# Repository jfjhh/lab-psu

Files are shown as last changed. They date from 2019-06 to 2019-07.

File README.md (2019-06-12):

# Lab Power Supply

This repository contains the KiCAD files and documentation for a simple lab
power supply.

The KiCAD files are in the top level.

The exported gerber and NC drill files are in the `gerbers` directory.

The documentation for the project is in the `doc` directory. This includes:

- KiCAD and DigiKey bills of materials in `doc/bom`.
- Datasheets for all ICs used in `doc/datasheets`.
- PCB layer PDFs in `doc/pcb`.
- A schematic PDF at `doc/psu-schematic.pdf`.
- A comprehensive manual in `doc/manual`.

Note that some parts on hand were used and not included in the DigiKey BOM.
These discrepancies are documented in `doc/bom/non-digikey.txt`.

*The development of this power supply was generously funded by the Reed College
Physics Department during the summer of 2019.*

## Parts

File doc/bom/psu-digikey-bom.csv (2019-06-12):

Manufacturer Part Number | Manufacturer | Digi-Key Part Number | Customer Reference | Reference Designator | Packaging | Part Status | Quantity | Unit Price | Extended Price | Quantity Available | Mfg Std Lead Time | Description | RoHS Status | Lead Free Status | REACH Status
LT3081EFE#PBF | Linear Technology/Analog Devices | LT3081EFE#PBF-ND |  |  | Tube | Active | 1 | 6.48000 | $6.48 | 459 | 8 Weeks | IC REG LIN POS ADJ 1.5A 16TSSOP | RoHS Compliant | Lead free | REACH Unaffected
LM334Z/NOPB | Texas Instruments | LM334ZNS/NOPB-ND |  |  | Box | Active | 1 | 0.87000 | $0.87 | 14066 | 16 Weeks | IC CURRENT SOURCE 3% TO92-3 | RoHS Compliant | Lead free | REACH Unaffected
PJ-002A | CUI Inc. | CP-002A-ND |  |  | Bag | Active | 1 | 0.60000 | $0.60 | 128622 | 10 Weeks | CONN PWR JACK 2X5.5MM SOLDER | RoHS Compliant | Lead free | Not Available
P160KN-0QC15B500K | TT Electronics/BI | 987-1304-ND |  |  | Tray | Active | 1 | 0.79000 | $0.79 | 745 | 10 Weeks | POT 500K OHM 1/5W PLASTIC LINEAR | RoHS Compliant | Lead free | REACH Unaffected
P160KN-0QC15B10K | TT Electronics/BI | 987-1301-ND |  |  | Tray | Active | 1 | 0.79000 | $0.79 | 4716 | 10 Weeks | POT 10K OHM 1/5W PLASTIC LINEAR | RoHS Compliant | Lead free | REACH Unaffected
LM4040EIM3X-2.5/NOPB | Texas Instruments | LM4040EIM3X-2.5/NOPBCT-ND |  |  | Cut Tape (CT) | Active | 1 | 0.44000 | $0.44 | 11631 | 1 Weeks | IC VREF SHUNT 2.5V SOT23-3 | RoHS Compliant | Lead free | REACH Unaffected
SK-14D01-G 6 | C&K | CKN10368-ND |  |  | Bulk | Active | 2 | 0.36000 | $0.72 | 2775 | 13 Weeks | SWITCH SLIDE SP4T 300MA 30V | RoHS Compliant | Lead free | REACH Unaffected
691137710002 | Wurth Electronics Inc. | 732-10955-ND |  |  | Box | Active | 1 | 0.38000 | $0.38 | 3902 | 16 Weeks | TERM BLK 2POS SIDE ENTRY 5MM PCB | RoHS Compliant | Lead free | REACH Unaffected
CL31A106MBHNNNE | Samsung Electro-Mechanics | 1276-6736-1-ND |  |  | Cut Tape (CT) | Active | 2 | 0.30000 | $0.60 | 298978 | Not Available | CAP CER 10UF 50V X5R 1206 | RoHS Compliant | Lead free | REACH Unaffected
TC33X-2-101E | Bourns Inc. | TC33X-101ECT-ND |  |  | Cut Tape (CT) | Active | 1 | 0.28000 | $0.28 | 749 | 18 Weeks | TRIMMER 100 OHM 0.1W J LEAD TOP | RoHS Compliant | Lead free | REACH Unaffected
CRCW12061R80FKEA | Vishay Dale | 541-1.80FFCT-ND |  |  | Cut Tape (CT) | Active | 1 | 0.10000 | $0.10 | 4595 | 14 Weeks | RES SMD 1.8 OHM 1% 1/4W 1206 | RoHS Compliant | Lead free | Not Available
RNCP1206FTD4R70 | Stackpole Electronics Inc | RNCP1206FTD4R70CT-ND |  |  | Cut Tape (CT) | Active | 1 | 0.10000 | $0.10 | 318328 | 18 Weeks | RES 4.7 OHM 1% 1/2W 1206 | RoHS Compliant | Lead free | REACH Unaffected
RC1206FR-0713RL | Yageo | 311-13.0FRCT-ND |  |  | Cut Tape (CT) | Active | 1 | 0.10000 | $0.10 | 205015 | 16 Weeks | RES SMD 13 OHM 1% 1/4W 1206 | RoHS Compliant | Lead free | REACH Unaffected
RMCF1206FT27R0 | Stackpole Electronics Inc | RMCF1206FT27R0CT-ND |  |  | Cut Tape (CT) | Active | 1 | 0.10000 | $0.10 | 18732 | 17 Weeks | RES 27 OHM 1% 1/4W 1206 | RoHS Compliant | Lead free | REACH Unaffected
CRGCQ1206F68R | TE Connectivity Passive Product | A129796CT-ND |  |  | Cut Tape (CT) | Active | 1 | 0.10000 | $0.10 | 63049 | 28 Weeks | CRGCQ 1206 68R 1% | RoHS Compliant | Lead free | Not Available
RNCP1206FTD100R | Stackpole Electronics Inc | RNCP1206FTD100RCT-ND |  |  | Cut Tape (CT) | Active | 2 | 0.10000 | $0.20 | 651800 | 18 Weeks | RES 100 OHM 1% 1/2W 1206 | RoHS Compliant | Lead free | REACH Unaffected
RNCP1206FTD180R | Stackpole Electronics Inc | RNCP1206FTD180RCT-ND |  |  | Cut Tape (CT) | Active | 1 | 0.10000 | $0.10 | 78712 | 18 Weeks | RES 180 OHM 1% 1/2W 1206 | RoHS Compliant | Lead free | REACH Unaffected
RNCP1206FTD1R00 | Stackpole Electronics Inc | RNCP1206FTD1R00CT-ND |  |  | Cut Tape (CT) | Active | 4 | 0.10000 | $0.40 | 600591 | 18 Weeks | RES 1 OHM 1% 1/2W 1206 | RoHS Compliant | Lead free | REACH Unaffected
RMCF1206FT39R0 | Stackpole Electronics Inc | RMCF1206FT39R0CT-ND |  |  | Cut Tape (CT) | Active | 1 | 0.10000 | $0.10 | 16042 | 17 Weeks | RES 39 OHM 1% 1/4W 1206 | RoHS Compliant | Lead free | REACH Unaffected
RC1206FR-071K5L | Yageo | 311-1.50KFRCT-ND |  |  | Cut Tape (CT) | Active | 1 | 0.10000 | $0.10 | 2341272 | 16 Weeks | RES SMD 1.5K OHM 1% 1/4W 1206 | RoHS Compliant | Lead free | REACH Unaffected
CRG1206F1M0 | TE Connectivity Passive Product | A106072CT-ND |  |  | Cut Tape (CT) | Active | 1 | 0.10000 | $0.10 | 190895 | 28 Weeks | RES SMD 1M OHM 1% 1/4W 1206 | RoHS Compliant | Lead free | Not Available
RC1206FR-0724KL | Yageo | 311-24.0KFRCT-ND |  |  | Cut Tape (CT) | Active | 1 | 0.10000 | $0.10 | 233935 | 16 Weeks | RES SMD 24K OHM 1% 1/4W 1206 | RoHS Compliant | Lead free | REACH Unaffected
RNCP1206FTD1K00 | Stackpole Electronics Inc | RNCP1206FTD1K00CT-ND |  |  | Cut Tape (CT) | Active | 2 | 0.10000 | $0.20 | 566298 | 18 Weeks | RES 1K OHM 1% 1/2W 1206 | RoHS Compliant | Lead free | REACH Unaffected
RMCF1206FT150K | Stackpole Electronics Inc | RMCF1206FT150KCT-ND |  |  | Cut Tape (CT) | Active | 1 | 0.10000 | $0.10 | 58922 | 17 Weeks | RES 150K OHM 1% 1/4W 1206 | RoHS Compliant | Lead free | REACH Unaffected
RMCF1206FT10K0 | Stackpole Electronics Inc | RMCF1206FT10K0CT-ND |  |  | Cut Tape (CT) | Active | 2 | 0.10000 | $0.20 | 1066955 | 17 Weeks | RES 10K OHM 1% 1/4W 1206 | RoHS Compliant | Lead free | REACH Unaffected
LM393ADR | Texas Instruments | 296-14605-1-ND |  |  | Cut Tape (CT) | Active | 1 | 0.36000 | $0.36 | 87570 | 1 Weeks | IC DUAL DIFF COMPARATOR 8-SOIC | RoHS Compliant | Lead free | REACH Unaffected
TC33X-2-504E | Bourns Inc. | TC33X-2-504ECT-ND |  |  | Cut Tape (CT) | Active | 1 | 0.28000 | $0.28 | 10204 | 18 Weeks | TRIMMER 500K OHM 0.1W J LEAD TOP | RoHS Compliant | Lead free | REACH Unaffected
LM317LCLP | Texas Instruments | 296-33312-5-ND |  |  | Bulk | Active | 2 | 0.43000 | $0.86 | 3029 | 16 Weeks | IC REG LIN POS ADJ 100MA TO92-3 | RoHS Compliant | Lead free | REACH Unaffected
111-0702-001 | Cinch Connectivity Solutions Johnson | J10125-ND |  |  | Bulk | Active | 1 | 3.57000 | $3.57 | 5967 | 6 Weeks | CONN BIND POST KNURLED RED | RoHS Compliant | Lead free | Not Available
111-0703-001 | Cinch Connectivity Solutions Johnson | J10126-ND |  |  | Bulk | Active | 1 | 2.98000 | $2.98 | 3052 | 6 Weeks | CONN BIND POST KNURLED BLACK | RoHS Compliant | Lead free | Not Available
151031SS06000 | Wurth Electronics Inc. | 732-5006-ND |  |  | Bulk | Active | 2 | 0.17000 | $0.34 | 5963 | 19 Weeks | LED RED DIFFUSED 3MM ROUND T/H | RoHS Compliant | Lead free | REACH Unaffected

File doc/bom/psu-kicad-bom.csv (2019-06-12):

Source: | /home/jfjhh/projects/lab-psu/psu.sch
Date: | Wed 12 Jun 2019 11:53:36 AM PDT
Tool: | Eeschema 5.1.0
Generator: | /usr/share/kicad/plugins/bom_csv_grouped_by_value.py
Component Count: | 60
Individual Components:
Item | Qty | Reference(s) | Value | LibPart | Footprint | Datasheet
 |  | C1 | 0u1 | Device:C_Small | Capacitor_THT:C_Disc_D5.0mm_W2.5mm_P2.50mm | ~
 |  | C2 | 0u1 | Device:C_Small | Capacitor_THT:C_Disc_D5.0mm_W2.5mm_P2.50mm | ~
 |  | C3 | 10u | Device:C_Small | Capacitor_SMD:C_1206_3216Metric_Pad1.42x1.75mm_HandSolder | ~
 |  | C4 | 10u | Device:C_Small | Capacitor_SMD:C_1206_3216Metric_Pad1.42x1.75mm_HandSolder | ~
 |  | C5 | 0u1 | Device:C_Small | Capacitor_THT:C_Disc_D5.0mm_W2.5mm_P2.50mm | ~
 |  | C6 | 0u1 | Device:C_Small | Capacitor_THT:C_Disc_D5.0mm_W2.5mm_P2.50mm | ~
 |  | C7 | 0u1 | Device:C_Small | Capacitor_THT:C_Disc_D5.0mm_W2.5mm_P2.50mm | ~
 |  | C8 | 0u1 | Device:C_Small | Capacitor_THT:C_Disc_D5.0mm_W2.5mm_P2.50mm | ~
 |  | D1 | LED_RED | Device:LED_ALT | LED_THT:LED_D3.0mm | ~
 |  | D2 | LED_RED | Device:LED_ALT | LED_THT:LED_D3.0mm | ~
 |  | J1 | Screw_Terminal_01x02 | Connector:Screw_Terminal_01x02 | TerminalBlock_MetzConnect:TerminalBlock_MetzConnect_Type094_RT03502HBLU_1x02_P5.00mm_Horizontal | ~
 |  | J2 | Barrel_Jack | Connector:Barrel_Jack | Connector_BarrelJack:BarrelJack_Horizontal | ~
 |  | J3 | Binding posts | Connector_Generic:Conn_01x02 | psu-foot:Binding Posts | ~
 |  | JP1 | Min Lim | Device:Jumper_NO_Small | Connector_PinHeader_2.54mm:PinHeader_1x02_P2.54mm_Vertical | ~
 |  | JP2 | No limit | Device:Jumper_NO_Small | Connector_PinHeader_2.54mm:PinHeader_1x02_P2.54mm_Vertical | ~
 |  | JP3 | Preload | Device:Jumper_NO_Small | Connector_PinHeader_2.54mm:PinHeader_1x02_P2.54mm_Vertical | ~
 |  | JP4 | Guard | Device:Jumper_NO_Small | psu-foot:Guard_Jumper | ~
 |  | JP5 | Guard | Device:Jumper_NO_Small | psu-foot:Guard_Jumper | ~
 |  | R1 | 1R8 | Device:R | Resistor_SMD:R_1206_3216Metric_Pad1.42x1.75mm_HandSolder | ~
 |  | R2 | 4R7 | Device:R | Resistor_SMD:R_1206_3216Metric_Pad1.42x1.75mm_HandSolder | ~
 |  | R3 | 13R | Device:R | Resistor_SMD:R_1206_3216Metric_Pad1.42x1.75mm_HandSolder | ~
 |  | R4 | 27R | Device:R | Resistor_SMD:R_1206_3216Metric_Pad1.42x1.75mm_HandSolder | ~
 |  | R5 | 68R | Device:R | Resistor_SMD:R_1206_3216Metric_Pad1.42x1.75mm_HandSolder | ~
 |  | R6 | 100R | Device:R | Resistor_SMD:R_1206_3216Metric_Pad1.42x1.75mm_HandSolder | ~
 |  | R7 | 180R | Device:R | Resistor_SMD:R_1206_3216Metric_Pad1.42x1.75mm_HandSolder | ~
 |  | R8 | 1R0 | Device:R | Resistor_SMD:R_1206_3216Metric_Pad1.42x1.75mm_HandSolder | ~
 |  | R9 | 2R2 | Device:R | Resistor_SMD:R_1206_3216Metric_Pad1.42x1.75mm_HandSolder | ~
 |  | R10 | 1R0 | Device:R | Resistor_SMD:R_1206_3216Metric_Pad1.42x1.75mm_HandSolder | ~
 |  | R11 | 1R0 | Device:R | Resistor_SMD:R_1206_3216Metric_Pad1.42x1.75mm_HandSolder | ~
 |  | R12 | 1R0 | Device:R | Resistor_SMD:R_1206_3216Metric_Pad1.42x1.75mm_HandSolder | ~
 |  | R13 | 39R | Device:R | Resistor_SMD:R_1206_3216Metric_Pad1.42x1.75mm_HandSolder | ~
 |  | R14 | 100R | Device:R | Resistor_SMD:R_1206_3216Metric_Pad1.42x1.75mm_HandSolder | ~
 |  | R15 | 4k7 | Device:R | Resistor_THT:R_Axial_DIN0207_L6.3mm_D2.5mm_P10.16mm_Horizontal | ~
 |  | R16 | 390R | Device:R | Resistor_THT:R_Axial_DIN0207_L6.3mm_D2.5mm_P10.16mm_Horizontal | ~
 |  | R17 | 1k5 | Device:R | Resistor_SMD:R_1206_3216Metric_Pad1.42x1.75mm_HandSolder | ~
 |  | R18 | 1M | Device:R | Resistor_SMD:R_1206_3216Metric_Pad1.42x1.75mm_HandSolder | ~
 |  | R19 | 24k | Device:R | Resistor_SMD:R_1206_3216Metric_Pad1.42x1.75mm_HandSolder | ~
 |  | R20 | 1k | Device:R | Resistor_SMD:R_1206_3216Metric_Pad1.42x1.75mm_HandSolder | ~
 |  | R21 | 150k | Device:R | Resistor_SMD:R_1206_3216Metric_Pad1.42x1.75mm_HandSolder | ~
 |  | R22 | 1k | Device:R | Resistor_THT:R_Axial_DIN0207_L6.3mm_D2.5mm_P10.16mm_Horizontal | ~
 |  | R23 | 22R | Device:R | Resistor_THT:R_Axial_DIN0207_L6.3mm_D2.5mm_P10.16mm_Horizontal | ~
 |  | R24 | 10k | Device:R | Resistor_SMD:R_1206_3216Metric_Pad1.42x1.75mm_HandSolder | ~
 |  | R25 | 10k | Device:R | Resistor_SMD:R_1206_3216Metric_Pad1.42x1.75mm_HandSolder | ~
 |  | R26 | 1k | Device:R | Resistor_SMD:R_1206_3216Metric_Pad1.42x1.75mm_HandSolder | ~
 |  | R27 | 100R | Device:R | Resistor_THT:R_Axial_DIN0207_L6.3mm_D2.5mm_P10.16mm_Horizontal | ~
 |  | R28 | 100R | Device:R | Resistor_THT:R_Axial_DIN0207_L6.3mm_D2.5mm_P10.16mm_Horizontal | ~
 |  | RV1 | 100R | Device:R_POT_US | psu-foot:Trim_pot_Bourns_TC33X-2-101E | ~
 |  | RV2 | 500k | Device:R_POT_US | Potentiometer_THT:Potentiometer_Piher_PC-16_Single_Horizontal | ~
 |  | RV3 | 10k | Device:R_POT_US | Potentiometer_THT:Potentiometer_Piher_PC-16_Single_Horizontal | ~
 |  | RV4 | 1k | Device:R_POT_US | Potentiometer_THT:Potentiometer_Piher_PC-16_Single_Horizontal | ~
 |  | RV5 | 500k | Device:R_POT_US | psu-foot:Trim_pot_Bourns_TC33X-2-101E | ~
 |  | SW1 | SW_SP4T | psu-sch:SW_SP4T | psu-foot:SP4T_CK_SK-14D01-G-6 | ~
 |  | SW2 | SW_SP4T | psu-sch:SW_SP4T | psu-foot:SP4T_CK_SK-14D01-G-6 | ~
 |  | SW3 | Lever toggle | Switch:SW_SPST | psu-foot:SW_SPST_Lever_Rubber | ~
 |  | U1 | LM4040DBZ-2.5 | Reference_Voltage:LM4040DBZ-2.5 | Package_TO_SOT_SMD:SOT-23 | http://www.ti.com/lit/ds/symlink/lm4040-n.pdf
 |  | U2 | LT3081 | psu-sch:LT3081 | Package_SO:HTSSOP-16-1EP_4.4x5mm_P0.65mm_EP3.4x5mm_Mask3x3mm_ThermalVias | https://www.analog.com/media/en/technical-documentation/data-sheets/3081fc.pdf
 |  | U3 | LM393 | Comparator:LM393 | Package_SO:SOIC-8_3.9x4.9mm_P1.27mm | http://www.ti.com/lit/ds/symlink/lm393-n.pdf
 |  | U4 | LM334M | Reference_Current:LM334M | Package_SO:SOIC-8_3.9x4.9mm_P1.27mm | http://www.ti.com/lit/ds/symlink/lm134.pdf
 |  | U5 | LM317L_TO92 | Regulator_Linear:LM317L_TO92 | Package_TO_SOT_THT:TO-92_Inline | http://www.ti.com/lit/ds/symlink/lm317l.pdf
 |  | U6 | LM317L_TO92 | Regulator_Linear:LM317L_TO92 | Package_TO_SOT_THT:TO-92_Inline | http://www.ti.com/lit/ds/symlink/lm317l.pdf
Collated Components:
Item | Qty | Reference(s) | Value | LibPart | Footprint | Datasheet
1 | 6 | C1, C2, C5, C6, C7, C8 | 0u1 | Device:C_Small | Capacitor_THT:C_Disc_D5.0mm_W2.5mm_P2.50mm | ~
2 | 2 | C3, C4 | 10u | Device:C_Small | Capacitor_SMD:C_1206_3216Metric_Pad1.42x1.75mm_HandSolder | ~
3 | 2 | D1, D2 | LED_RED | Device:LED_ALT | LED_THT:LED_D3.0mm | ~
4 | 1 | J1 | Screw_Terminal_01x02 | Connector:Screw_Terminal_01x02 | TerminalBlock_MetzConnect:TerminalBlock_MetzConnect_Type094_RT03502HBLU_1x02_P5.00mm_Horizontal | ~
5 | 1 | J2 | Barrel_Jack | Connector:Barrel_Jack | Connector_BarrelJack:BarrelJack_Horizontal | ~
6 | 1 | J3 | Binding posts | Connector_Generic:Conn_01x02 | psu-foot:Binding Posts | ~
7 | 1 | JP1 | Min Lim | Device:Jumper_NO_Small | Connector_PinHeader_2.54mm:PinHeader_1x02_P2.54mm_Vertical | ~
8 | 1 | JP2 | No limit | Device:Jumper_NO_Small | Connector_PinHeader_2.54mm:PinHeader_1x02_P2.54mm_Vertical | ~
9 | 1 | JP3 | Preload | Device:Jumper_NO_Small | Connector_PinHeader_2.54mm:PinHeader_1x02_P2.54mm_Vertical | ~
10 | 2 | JP4, JP5 | Guard | Device:Jumper_NO_Small | psu-foot:Guard_Jumper | ~
11 | 1 | R1 | 1R8 | Device:R | Resistor_SMD:R_1206_3216Metric_Pad1.42x1.75mm_HandSolder | ~
12 | 1 | R2 | 4R7 | Device:R | Resistor_SMD:R_1206_3216Metric_Pad1.42x1.75mm_HandSolder | ~
13 | 1 | R3 | 13R | Device:R | Resistor_SMD:R_1206_3216Metric_Pad1.42x1.75mm_HandSolder | ~
14 | 1 | R4 | 27R | Device:R | Resistor_SMD:R_1206_3216Metric_Pad1.42x1.75mm_HandSolder | ~
15 | 1 | R5 | 68R | Device:R | Resistor_SMD:R_1206_3216Metric_Pad1.42x1.75mm_HandSolder | ~
16 | 2 | R6, R14 | 100R | Device:R | Resistor_SMD:R_1206_3216Metric_Pad1.42x1.75mm_HandSolder | ~
17 | 1 | R7 | 180R | Device:R | Resistor_SMD:R_1206_3216Metric_Pad1.42x1.75mm_HandSolder | ~
18 | 4 | R8, R10, R11, R12 | 1R0 | Device:R | Resistor_SMD:R_1206_3216Metric_Pad1.42x1.75mm_HandSolder | ~
19 | 1 | R9 | 2R2 | Device:R | Resistor_SMD:R_1206_3216Metric_Pad1.42x1.75mm_HandSolder | ~
20 | 1 | R13 | 39R | Device:R | Resistor_SMD:R_1206_3216Metric_Pad1.42x1.75mm_HandSolder | ~
21 | 1 | R15 | 4k7 | Device:R | Resistor_THT:R_Axial_DIN0207_L6.3mm_D2.5mm_P10.16mm_Horizontal | ~
22 | 1 | R16 | 390R | Device:R | Resistor_THT:R_Axial_DIN0207_L6.3mm_D2.5mm_P10.16mm_Horizontal | ~
23 | 1 | R17 | 1k5 | Device:R | Resistor_SMD:R_1206_3216Metric_Pad1.42x1.75mm_HandSolder | ~
24 | 1 | R18 | 1M | Device:R | Resistor_SMD:R_1206_3216Metric_Pad1.42x1.75mm_HandSolder | ~
25 | 1 | R19 | 24k | Device:R | Resistor_SMD:R_1206_3216Metric_Pad1.42x1.75mm_HandSolder | ~
26 | 2 | R20, R26 | 1k | Device:R | Resistor_SMD:R_1206_3216Metric_Pad1.42x1.75mm_HandSolder | ~
27 | 1 | R21 | 150k | Device:R | Resistor_SMD:R_1206_3216Metric_Pad1.42x1.75mm_HandSolder | ~
28 | 1 | R22 | 1k | Device:R | Resistor_THT:R_Axial_DIN0207_L6.3mm_D2.5mm_P10.16mm_Horizontal | ~
29 | 1 | R23 | 22R | Device:R | Resistor_THT:R_Axial_DIN0207_L6.3mm_D2.5mm_P10.16mm_Horizontal | ~
30 | 2 | R24, R25 | 10k | Device:R | Resistor_SMD:R_1206_3216Metric_Pad1.42x1.75mm_HandSolder | ~
31 | 2 | R27, R28 | 100R | Device:R | Resistor_THT:R_Axial_DIN0207_L6.3mm_D2.5mm_P10.16mm_Horizontal | ~
32 | 1 | RV1 | 100R | Device:R_POT_US | psu-foot:Trim_pot_Bourns_TC33X-2-101E | ~
33 | 1 | RV2 | 500k | Device:R_POT_US | Potentiometer_THT:Potentiometer_Piher_PC-16_Single_Horizontal | ~
34 | 1 | RV3 | 10k | Device:R_POT_US | Potentiometer_THT:Potentiometer_Piher_PC-16_Single_Horizontal | ~
35 | 1 | RV4 | 1k | Device:R_POT_US | Potentiometer_THT:Potentiometer_Piher_PC-16_Single_Horizontal | ~
36 | 1 | RV5 | 500k | Device:R_POT_US | psu-foot:Trim_pot_Bourns_TC33X-2-101E | ~
37 | 2 | SW1, SW2 | SW_SP4T | psu-sch:SW_SP4T | psu-foot:SP4T_CK_SK-14D01-G-6 | ~
38 | 1 | SW3 | Lever toggle | Switch:SW_SPST | psu-foot:SW_SPST_Lever_Rubber | ~
39 | 1 | U1 | LM4040DBZ-2.5 | Reference_Voltage:LM4040DBZ-2.5 | Package_TO_SOT_SMD:SOT-23 | http://www.ti.com/lit/ds/symlink/lm4040-n.pdf
40 | 1 | U2 | LT3081 | psu-sch:LT3081 | Package_SO:HTSSOP-16-1EP_4.4x5mm_P0.65mm_EP3.4x5mm_Mask3x3mm_ThermalVias | https://www.analog.com/media/en/technical-documentation/data-sheets/3081fc.pdf
41 | 1 | U3 | LM393 | Comparator:LM393 | Package_SO:SOIC-8_3.9x4.9mm_P1.27mm | http://www.ti.com/lit/ds/symlink/lm393-n.pdf
42 | 1 | U4 | LM334M | Reference_Current:LM334M | Package_SO:SOIC-8_3.9x4.9mm_P1.27mm | http://www.ti.com/lit/ds/symlink/lm134.pdf
43 | 2 | U5, U6 | LM317L_TO92 | Regulator_Linear:LM317L_TO92 | Package_TO_SOT_THT:TO-92_Inline | http://www.ti.com/lit/ds/symlink/lm317l.pdf

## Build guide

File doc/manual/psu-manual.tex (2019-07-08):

\documentclass[letterpaper,twocolumn,11pt]{article}

\usepackage[utf8]{inputenc}
\usepackage[T1]{fontenc}
\usepackage{amsmath}
\usepackage{amssymb}
\usepackage{amsthm}
\usepackage{booktabs}
\usepackage[labelfont=bf]{caption}
\usepackage[american]{circuitikz}
\usepackage{enumitem}
\usepackage{float}
\usepackage{geometry}
\usepackage{graphicx}
\usepackage{hyperref}
\usepackage{mathtools}
\usepackage{microtype}
\usepackage{nicefrac}
\usepackage{pdfpages}
\usepackage{physics}
\usepackage{rotating}
\usepackage{siunitx}
\usepackage{xcolor}

\geometry{margin=1in}

\newcommand{\refdes}[1]{\texttt{#1}}
\newcommand{\wtemp}{\ensuremath{\blacklozenge}}

% \renewcommand{\includepdf}{}

\title{Lab Power Supply Manual \\ \large Rev. B}
\author{Alex Striff}
\date{\today}

\begin{document}
\maketitle
\tableofcontents
\listoftables
\thispagestyle{empty}

\section*{Colophon}

The schematic diagram and printed circuit board layout were both created with
KiCAD. This manual was compiled using \LaTeX. Relatively fine (\SI{0.51}{\mm})
lead-based solder and mildly activated rosin flux were required to solder the
components to the PCB.

\section{Acknowledgments}

The creation of this lab power supply was generously funded by the Reed College
Physics Department. I would like to thank Edgar Perez for his kind advice, as
well as Lucas Illing for supporting this project.

\section{Motivation}

Often when working in electronics, several voltage sources are needed. In
addition to a main power rail, one may need a complementary negative power rail
for analog circuitry, or a different logic power supply at \SI{3.3}{\V} instead
of \SI{5}{\V}. Low-impedance bias voltages are also a frequent requirement,
needed for biasing BJTs, comparator inputs, and more.

For most applications, a power supply fulfilling the requirements of these
applications need not be capable of supplying much more than \SI{1}{\A} of
current, must have a stable voltage output (requiring a linear regulator), and
must have a current limiting function.  Additionally, it would be nice if the
power supply was much smaller than a conventional \SI{30}{\V}, \SI{3}{\A} output
bench power supply with a large transformer, being conveniently powered from a
common wall plug, batteries, or any other DC power source at hand. I have
attempted to construct such a power supply.

\section{Safety Notice (Grounding)}

Please note that the negative voltage output of the supply is directly connected
to the negative voltage input to the supply. That is, the output voltage of the
supply floating relative to earth ground if and only if the input voltage is
floating.

If you are uncertain if the supply (or any other piece of equipment) is
floating, it is quick and simple to check if this is the case. Set a digital
multimeter to its resistance measurement or continuity check mode. Connect one
probe to the negative output of the PSU (the black five-way binding post) or to
the other terminal in question, and then connect the other probe to earth
ground. This can be done either by insertion in to the \emph{earth} socket of a
wall outlet, or by touching the outside of a BNC connector on any nearby
oscilloscopes, as these are almost always earth grounded. If inserting into a
wall outlet, be certain that you know which hole is which, and that you are
using a multimeter approved for wall testing (most are).

If the output is not floating (earth-referenced), then one must be careful to
only connect oscilloscope ground leads to the negative output of the supply.
Whatever the ground lead is connected to will be shorted to earth ground. If an
incorrect connection is made, then connected circuit components, oscilloscopes,
or computers (\textit{e.g.} through USB) may be damaged. If you are uncertain,
connect probes as if the circuit is not floating.

If the output is floating (or if you know which terminals are earthed and which
are not), then the supply may be safely connected to other voltage sources in
whatever configurations are convenient, such as in a dual-rail setup.

\section{Usage Instructions}

\subsection{Setting the output voltage}

Connect a voltmeter to the output of the supply. You may use either the binding
posts or the test points labeled on the board to achieve this. Turn the PSU on
and adjust the voltage using the \emph{coarse} and \emph{fine} adjustment knobs
as needed. Note that the maximum output voltage is about \SI{1.5}{\V} below the
input voltage.

\subsection{Setting the current limit}\label{sec:set_limit}

To set the current limit to its minimum value, \emph{short} the minimum limit
jumper (labeled \emph{Min Lim}, \refdes{JP1}). To set the current limit to
higher than this value, the jumper must be \emph{open}.

The current limit is set to fixed values by moving the switches on the
board. The default values are 1, 2.5, 5, 10, 25, 50, and \SI{100}{\mA}. To set
the limit to any of the upper four values, the switch for the lower values must
be in its rightmost position, as indicated on the board.

Alternatively, the switch section on the board may not be populated, and a
\SI{10}{\kohm} (preferably 10-turn) potentiometer (\refdes{RV4}) may be
soldered in to provide a continuously variable current limit.

To set the current limit to its maximum value, \emph{open} the no limit jumper
(labeled \emph{No Limit}, \refdes{JP2}). To set the current limit to lower than
this value, the jumper must be \emph{shorted}. The maximum value is about
\SI{2.0}{\A} in normal operation, and less when the device shuts down to prevent
overheating.

\subsection{Indicator LEDs}

The power supply includes two indicator LEDs for when output voltage regulation
is not guaranteed.

The \textit{Hot} indicator LED (\refdes{D2}) lights when the main regulation IC
(see Section~\ref{sec:lt3081}) starts to get hot (when the junction temperature
is about \SI{100}{\celsius} or above). This light is a warning, and the output
should continue to be regulated as normal. If the IC continues to heat up (to a
junction temperature of \SI{125}{\celsius}), then internal protection circuitry
will prevent damage and reduce the output voltage.

The \textit{$V_\text{out}$ Error ($I$ lim)} indicator LED (\refdes{D1}) lights
when the actual output voltage is not sufficiently close to the set output
voltage. The most common cause for this is if the current limiting function is
active, but internal protection circuitry or a set voltage that is too high may
also cause an output error.

\subsection{Monitoring the output current}

If it is not preferred to use an ammeter to measure the output current, the
\textit{$I_\text{out}$} test point is provided for convenient measurement or
external control of the load current. The signal at \textit{$I_\text{out}$}
is one volt for every ampere of output current, \emph{including the internal
load} (see Table~\ref{tab:chars} and Section~\ref{sec:int_load}). For example,
if the supply is outputting \SI{25}{\mA} total, then \textit{$I_\text{out}$}
should read \SI{25}{\mV}.

\subsection{Monitoring the internal temperature}

For more quantitative information about the temperature of the main regulation
IC (see Section~\ref{sec:lt3081}) than is provided by the \textit{Hot} indicator
LED, the \textit{Temp} test point is provided. The signal at \textit{Temp} is
one millivolt for every degree Celsius of junction temperature. For example, if
the junction temperature of the IC is about \SI{73}{\celsius} (subject to
variation inside the IC), then \textit{Temp} should read \SI{73}{\mV}.

\subsection{Disabling the internal load}

The internal load may be disabled by \emph{opening} the \textit{Internal Load}
jumper.  Note that this will increase the current limit by at most \SI{4}{\mA}
above the current limit displayed on the switches or that previously set by
\refdes{RV4}, if installed. For most purposes, the \textit{Internal Load} jumper
should be in its normal, \emph{shorted} position (see
Section~\ref{sec:int_load}).

\subsection{Calibrating the current limit}

The power supply requires a minimum load in order to regulate the output voltage
properly. An internal load usually supplies this minimum load (see
Section~\ref{sec:int_load}), but this offsets the effective current limit on the
output. A trimmer potentiometer is provided to compensate for this offset.

First, choose which current limit range you most value precision on, say
the \SI{10}{\mA} range. Set the supply to a relatively low voltage, like
\SI{1}{\V}, and place the appropriate load on the output of the supply with a
potentiometer. In this case, we would adjust a potentiometer until it drew
\SI{10}{\mA} through itself. The \textit{$V_\text{out}$ Error ($I$ lim)}
indicator LED should be off. Measuring \textit{$I_\text{out}$} should show
about \SI{13}{\mV}, corresponding the \SI{10}{\mA} external load and the (fixed)
\SI{3}{\mA} internal load. Using a screwdriver, adjust the potentiometer (labeled \emph{Load
Offset}, \refdes{RV1}) until the output voltage is stable (no current limiting),
and then carefully reverse direction and adjust until the current limit just
starts to activate. This may be judged by checking the output voltage with a
voltmeter, or by using the built-in indicator if it is calibrated as described
in Section~\ref{sec:cal_offset}. If using a voltmeter (the more precise method),
aim for a limit situation where the output is about \SI{10}{\mV} below the set
(stable) voltage.

\subsection{Calibrating the output error indicator}\label{sec:cal_offset}

The issues associated with creating a reliable output error indicator are
discussed in Section~\ref{sec:how_offset}. If necessary, a trimmer potentiometer
(\refdes{RV5}) may be populated to correct the default setting by the resistor
\refdes{R21}.

Attach a voltmeter to the PSU and set the output voltage to \SI{1}{\V}. Attach
an external potentiometer to the output of the supply, valued to draw a typical
current for your application. Set the PSU current limit so that increasing the
load current will trigger the limit function. If the \SI{1}{\V} output does not
demand enough current, it may be increased, but try to keep it as low as
possible (see \ref{sec:how_offset} for why). Wait until the temperature of the
circuit has stabilized. Error on the side of drawing a slightly lower current
than needed, depending on the sensitivity required (see below). Increase the
load gradually, and watch the error indicator LED (\refdes{D1}).

If the default indication threshold set by \refdes{R21} is not sensitive enough
for your needs, solder in the \SI{500}{\kohm} \refdes{RV5} and try the
adjustment procedure below.

If this does not work, or if the default indication did not work at all, solder
in \refdes{RV5} and \emph{remove} \refdes{R21}. This provides a wider range of
variation for the indication threshold, at the cost of a coarser adjustment
rate.

With the potentiometer \refdes{RV5} and the default resistor \refdes{R21}
soldered on the board or not depending on your needs, adjust the external load
potentiometer until the output is 2 -- \SI{10}{\mV} below the set voltage. If
you intend to use the supply \emph{only} above about \SI{5}{\V}, the lower the
better (you may even be able to remove \refdes{RV5} and wire a short across
\refdes{R21} for a bit more sensitivity). To complete the calibration, adjust
\refdes{RV5} to the barrier where \refdes{D1} just barely lights, or perhaps
flickers.

% \section{Electrical Characteristics}

\begin{table*}[ht]
  \centering
  \caption[Electrical Characteristics]{Electrical characteristics. The \wtemp\
    mark indicates specifications which apply over the full operating
    temperature range. Otherwise, specifications are at (junction) temperatures
    of \SI{25}{\celsius}. Note that application of negative input voltages may
    damage the supply. Specifically, such damage tends to disable any current
    limiting functionality, while maintaining the capability for voltage
  regulation.}
  \resizebox{\textwidth}{!}{%
    \begin{tabular}{lr|lr|cccr}
      \toprule
      \multicolumn{2}{c}{\textbf{Parameter}} &
      \multicolumn{2}{c}{\textbf{Conditions}} & \textbf{Min} & \textbf{Typ} &
      \textbf{Max} & \multicolumn{1}{c}{\textbf{Units}} \\
      \midrule
      Input Voltage & $V_\text{in}$ & & \wtemp & 5.0 & & 32.0 & \si{\V} \\

      Output Voltage & $V_\text{out}$
      & $I_\text{load} < I_\text{lim}$, $V_\text{in} < \SI{16}{\V}$ & \wtemp
      & 0.7 & & $V_\text{in} - V_\text{do}$ & \si{\V} \\
      &
      & $I_\text{load} < I_\text{lim}$, $V_\text{in} \ge \SI{16}{\V} & \wtemp
      & 0.7 & & 16 & \si{\V} \\
      &
      & No internal load & \wtemp
      & 0.0 & & & \si{\V} \\

      Dropout Voltage & $V_\text{do}$
      & $I_\text{load} = \SI{100}{\mA}$ & & & 1.21 & & \si{\V} \\
      &
      & $I_\text{load} = \SI{1.5}{\A}$ & \wtemp & & 1.23 & 1.5 & \si{\V} \\

      Internal Current Limit & $I_\text{max}$ & $V_\text{in} = \SI{5}{\V}$,
      $V_\text{set} = \SI{0}{\V}$, $V_\text{out} = \SI{-0.1}{\V}$ & \wtemp
      & 1.5 & 2.0 & & \si{\A} \\

      $I_\text{out}$ Relative Error & & $I_\text{load} = \SI{1.5}{\A}$ &
      & 0 & 6 & 11 & \si{\percent} \\

      $I_\text{out}$ Operating Range & & & \wtemp
      & $V_\text{out} - \SI{40}{\V}$ & & $V_\text{out} + \SI{0.4}{\V}$
      & \si{\V} \\

      \textit{Temp} Absolute Error &
      & $\SI{0}{\celsius} \le T_J \le \SI{125}{\celsius}$ &
      & -10 & & 10 & \si{\uA} \\
      &
      & $\SI{125}{\celsius} < T_J \le \SI{150}{\celsius}$ &
      & -15 & & 15 & \si{\uA} \\

      Ripple Rejection
      & PSRR & $f = \SI{120}{\Hz}$ & & 75 & 90 & & \si{\dB} \\

      $V_\text{ripple} = \SI{0.5}{V_{\text{pp}}}$,
      $I_\text{load} = \SI{0.1}{\A}$, &
      & $f = \SI{10}{\kHz}$ & & & 75 & & \si{\dB} \\

      $V_\text{in} = V_\text{out(nom)} + \SI{3}{\V}$ &
      & $f = \SI{1}{\MHz}$ & & & 20 & & \si{\dB} \\

      Internal Load & $I_\text{int}$ & & \wtemp & 2 & 3 & 4 & \si{\mA} \\
      \bottomrule
  \end{tabular}}
  \label{tab:chars}
\end{table*}

\section{Principles of Operation}

\subsection{The LT3081 linear regulator}\label{sec:lt3081}

All of the regulation that the power supply provides is done by the LT3081, a
rugged linear regulator IC. The regulation circuitry is depicted in
Figure~\ref{fig:reg_circ}. An internal current source of \SI{50}{\uA} allows the
set voltage to be configured with a single resistor $R_\text{set}$. In the power
supply, $R_\text{set}$ is determined by the two potentiometers \refdes{RV2} and
\refdes{RV3}.

If $V_\text{out} < V_\text{set}$, then the error amplifier will increase the
base voltage of the NPN transistor until the entire Sziklai pair has
$V_\text{set}$ at its emitter. Similarly, the base voltage will be suitably
reduced if $V_\text{out} > V_\text{set}$. In this way, the output voltage is
regulated by a negative feedback loop.

In practice, it may be difficult to stabilize such a circuit constructed of
discrete components against oscillation. Using an integrated circuit solution
such as the LT3081 allows us to have matched transistors at close to the same
temperature, as well as to take advantage of the work done by previous engineers
to make the output voltage stable. We simply add on some additional capacitances
(\refdes{C1} to \refdes{C4} and \refdes{C8}) to improve noise characteristics,
transcient performance, and stability a bit more.

\begin{figure}
  \centering
  \begin{circuitikz} \draw
    (0,0) node[op amp,yscale=-1] (opamp) {}
    (-3,0.5) to [short] (opamp.+)
    (-3,2.5) to [short,-o] (3.5,2.5)
    node[anchor=west]{$V_{\text{in}}$} (vin)
    (-3,2.5) to [american current source,l=\SI{50}{\uA}] (-3,0.5)
    (-3,0.5) to [R,l=$R_\text{set}$,*-] (-3,-1.5)
    node [ground] {}
    (opamp.out) node[npn,anchor=B] (npn) {} (npn.collector)
    (npn.collector) node[pnp,anchor=B] (pnp) {} (pnp.collector)
    (pnp.collector) to [short,-*] ($(pnp.collector)+(0,-1.5))
    (pnp.emitter) to [short,-*] ($(pnp.emitter)+(0,0.9625))
    (opamp.-) to [short] ($(opamp.-)+(0,-1))
    to [short,-o] (3.5,-1.5) node[anchor=west]{$V_\text{out}$}
    (npn.emitter) to [short,-*] ($(npn.emitter)+(0,-0.725));
  \end{circuitikz}
  \caption{The equivalent voltage regulation circuitry inside the LT3081. The
    equivalent current regulation circuitry is not depicted here or in the
  LT3081 datasheet.}
  \label{fig:reg_circ}
\end{figure}

\subsection{The internal load}\label{sec:int_load}

Given the requirement that any circuitry used in the power supply must function
consistently over the entire range of $V_\text{in}$, a simple resistor (as in
the LT3081 datasheet) \emph{cannot} be used as a means of meeting the minimum
load requirement of the LT3081. Instead, the LM334 current source (\refdes{U4})
was used. With \refdes{R23} set to \SI{22}{\ohm}, we expect about \SI{3.1}{\mA}
to be sunk from the output of the power supply, which is well above the minimum
load requirement of the LM3081, over temperature. Since we are manually nulling
the offset due to this current, it is allowable to use a common through-hole
\SI{5}{\percent} tolerance resistor for \refdes{R23}, but if your application
requires precise current limiting over a wide and changing range of
temperatures, a \SI{1}{\percent} or better tolerance resistor should be used for
added thermal stability.

\subsection{The \textit{Hot} indicator circuit}\label{sec:how_hot}

To establish a precise voltage of \SI{100}{\mV} over the entire range of
$V_\text{in}$, corresponding to a junction temperature of \SI{100}{\celsius}, a
\SI{2.5}{\V} LM4040 voltage reference (\refdes{U1}) and a voltage divider were
used. The LM393 comparator (\refdes{U3B}) compares the \textit{Temp} output to
this reference temperature, and is configured to pull the open collector output
of the comparator low if the \textit{Temp} output goes above the reference. This
connects the indicator LED to ground. A LM317 (\refdes{U6}) configured as a
current source supplies a stable current to the LED over the full range of
$V_\text{in}$. Inspection of the circuit shows that errors introduced by
resistor tolerances and comparator input offset currents and voltages will
result in an absolute error of at most \SI{5}{\celsius}. Furthermore, the
comparator operates without hysteresis, so the LED may flicker when the
actual and reference temperatures coincide. For the purpose of a coarse
temperature indication, these undesirable characteristics are inconsequential.

\subsection{The $V_\text{out}$ error indicator circuit}\label{sec:how_offset}

The general configuration of the $V_\text{out}$ error indicator circuit is
similar to that of the \textit{Hot} indicator circuit, described in
Section~\ref{sec:how_hot}. However, the error introduced by that circuit is
unacceptable for the purpose of displaying the current status of regulation.
Additionally, we \emph{expect} the output voltage to coincide \emph{precisely}
(to within a few millivolts) with the set voltage. Without any correction, the
LED may reasonably indicate an error indefinitely, or at least flicker, when the
output voltage is actually well-regulated.

The standard solution that one may propose is to add hysteresis (in the form of
a Schmitt trigger) to the comparator. This will not work. A Schmitt trigger must
have an upper trigger threshold that lies \emph{above} the set voltage, but in
the course of recovering from current limiting, the output voltage may never
overshoot the set voltage. Thus the threshold will never be crossed, and the
error indicator may remain on indefinitely. What is needed instead, is a small
offset.

If the comparator recieved a set voltage that was, say, \SI{10}{\mV} below
$V_\text{set}$, then the problem is solved. Hysteresis is not even needed, since
most all causes for a failure in regulation will not manifest as a steady offset
of \SI{10}{\mV}. But how can we create such a small offset over the entire range
of $V_\text{out}$, especially when the offset is comparable in size to all of
the sources of error involved? The main barriers to control that must be
addressed include
\begin{itemize}
  \item Resistor tolerances,
  \item Loading of input sources,
  \item Comparator input offset voltage,
  \item Comparator input bias current,
  \item Comparator input offset current, and
  \item Noise.
\end{itemize}

Since the entire point of adding the offset is to allow for errors, we can deal
with the comparator input offset voltage and current by lumping in the effect of
their worst-case absolute errors with the error in regulation. This increases
the minimum offset needed from that due to regulation, but only to about the
\SI{10}{\mV} stated before. However, we cannot increase the offset too much: at
an output voltage of \SI{1.00}{\V}, an offset of \SI{10}{\mV} already represents
a \SI{1}{\percent} error in indication. The aim is to keep this level of
precision for set voltages from \SI{1.00}{\V} to \SI{30.0}{\V}. If better
precision than about \SI{10}{\percent} is needed below about \SI{100}{\mV}, the
calibration procedure detailed in Section~\ref{sec:cal_offset} may be done at
the necessary low voltage, at the cost of less realiable indication at higher
voltages of \SI{10}{\V} to \SI{30}{\V}, depending on the configuration.

So how are we to obtain the offset? Since the input bias current of the
comparator may introduce errors comparable to the offset, we can change
perspective. The ``error'' that it introduces can in fact be \emph{used} as the
offset. The LM393 and many other common differential-input analog devices such
as the LM358 have PNP darlington pair input stages. This means that any input
bias current will flow \emph{out} of the input terminals, conveniently allowing
us to place a resistor on the \emph{noninverting} input of the comparator to
achieve an offset in the correct direction. Since the noninverting input is
connected to the low-impedance $V_\text{out}$, the offset voltage introduced may
be reliably predicted as $I_\text{in(+)} R_\text{off}$ (see
Figure~\ref{fig:biasoff}). For the typical $I_\text{in(+)} = \SI{25}{\nA}$ and
$R_\text{off} = \SI{150}{\kohm}$ (\refdes{R21}), we obtain an offset of
\SI{3.8}{\mV}. This should handle possible offsets due to comparator input
offset voltage and regulation of up to \SI{3}{\mV}, and more offset may be
provided with a potentiometer as described in Section~\ref{sec:cal_offset}.

\begin{figure}
  \centering
  \begin{circuitikz} \draw
    (0,0) node[op amp,anchor=+,label={[label distance=0.5cm]-60:LM393}]
    (opamp) {}
    (-2.5,0) node[anchor=east]{$V_\text{out}$}
    to [R,l=$R_\text{off}$,v<=$I_\text{in(+)} R_\text{off}$,o-] (-0.5,0)
    to [short,i<=$I_{in(+)}$] (0,0)
    (opamp.down) node[ground] {}
    (opamp.up) to [short,-o] ($(opamp.up)+(0,0.5))
    node[anchor=south]{$V_\text{in}$}
    ;
    \draw[densely dashed]
    (opamp.-) to [short] ($(opamp.-)+ (-0.5,0))
    (opamp.out) to [short] ($(opamp.out)+ (0.5,0))
    ;
  \end{circuitikz}
  \caption{Introducing a small voltage offset by exploiting the input bias
  current of the LM393 comparator.}
  \label{fig:biasoff}
\end{figure}

But there is a problem with this circuit. Let's take a closer look at the input
bias current. While datasheets like that for the LM393 give the input bias
current at \SI{0}{\V} common mode voltage, we must know it for all common mode
voltages up to $V_\text{in}$. The LM358 has a simpler input stage than the
LM393, so let's look at it instead to understand what is going on. Some quick
measurements reveal that the offset voltage we are after \emph{decreases} with
increasing common mode voltage (Figure~\ref{fig:lm358}). For simplicity, we may
treat this decrease as linear, as we will only be operating in the approximately
linear region.

Thus our solution does not work well at high common mode voltages. We fix this
by adding a high-ratio voltage divider on the other input to the comparator.
Note that for a voltage divider with gain close to unity ($R_1 \ll R_2$),
\[
  A_V
  = \frac{R_b}{R_a + R_b}
  = \frac{1}{1 + \flatfrac{R_a}{R_b}}
  \approx 1 - \flatfrac{R_a}{R_b}.
\]
Thus with \SI{1}{\percent} resistors, we expect a relative error of about
\SI{1.4}{\percent} in $\flatfrac{R_a}{R_b}$. For the values actually used
(\refdes{R17} and \refdes{R18}), we then obtain an absolute error of
\SI{21}{\uV} per volt in, giving a worst case \SI{0.6}{\mV} error for a
\SI{30}{\V} input. Not bad.

\begin{figure}
  \centering
  \input{offsets}
  \caption{In the configuration of Figure~\ref{fig:biasoff}, the offset voltage
    due to the input bias current of the LM358 decreases with increasing common
  mode voltage.}
  \label{fig:lm358}
\end{figure}

Now that we know why, a quick analysis of the actual offset circuit, where we
have both offset methods acting together, gives the characteristic plot of
Figure~\ref{fig:final_off}. Values were chosen to give an increasing offset with
common mode, rather than the constant offset originally discussed, for
additional margin and a more understandable relative-drop trigger, rather than
an offset trigger. This way, the higher voltage ranges do not seem more
sensitive to loading than the lower ranges.

\begin{figure}
  \centering
  \input{off}
  \caption{The expected offsets from the full offset circuit for varying values
  of $R_f$.}
  \label{fig:final_off}
\end{figure}

\clearpage
% \section{Schematic Diagram}

\includepdf[pages=-,pagecommand={},angle=90,addtotoc={1,section,1,Schematic
Diagram,fig:schematic}]{../psu-schematic.pdf}

\section{Printed Circuit Board Layers}

\includepdf[pages=-,pagecommand={},noautoscale=true,angle=90,addtotoc={1,subsection,2,Front
    Copper,fig:psu-F_Cu}]{../pcb/psu-F_Cu.pdf}
\includepdf[pages=-,pagecommand={},noautoscale=true,angle=90,addtotoc={1,subsection,2,Back
    Copper,fig:psu-B_Cu}]{../pcb/psu-B_Cu.pdf}
\includepdf[pages=-,pagecommand={},noautoscale=true,angle=90,addtotoc={1,subsection,2,Front
    Solder Mask,fig:psu-F_Mask}]{../pcb/psu-F_Mask.pdf}
\includepdf[pages=-,pagecommand={},noautoscale=true,angle=90,addtotoc={1,subsection,2,Back
    Solder Mask,fig:psu-B_Mask}]{../pcb/psu-B_Mask.pdf}
\includepdf[pages=-,pagecommand={},noautoscale=true,angle=90,addtotoc={1,subsection,2,Front
    Silk Screen,fig:psu-F_SilkS}]{../pcb/psu-F_SilkS.pdf}
\includepdf[pages=-,pagecommand={},noautoscale=true,angle=90,addtotoc={1,subsection,2,Front
    Fabrication,fig:psu-F_Fab}]{../pcb/psu-F_Fab.pdf}
\includepdf[pages=-,pagecommand={},noautoscale=true,angle=90,addtotoc={1,subsection,2,Plated
    Through-Hole Drill Map,fig:psu-PTH-drl_map}]{../pcb/psu-PTH-drl_map.pdf}
\includepdf[pages=-,pagecommand={},noautoscale=true,angle=90,addtotoc={1,subsection,2,Non-Plated
    Through-Hole Drill Map,fig:psu-NPTH-drl_map}]{../pcb/psu-NPTH-drl_map.pdf}
\includepdf[pages=-,pagecommand={},noautoscale=true,angle=90,addtotoc={1,subsection,2,User
    Comments,fig:psu-Cmts_User}]{../pcb/psu-Cmts_User.pdf}
\includepdf[pages=-,pagecommand={},noautoscale=true,angle=90,addtotoc={1,subsection,2,Edge
    Cuts (Board Outline),fig:psu-Edge_Cuts}]{../pcb/psu-Edge_Cuts.pdf}

% \section{Bill of Materials}

\begin{sidewaystable*}[ht]
  \caption[Bill of Materials]{Bill of materials with collated items. There are
  60 components total.}
  \resizebox{\linewidth}{!}{%
    \begin{tabular}{cclllll}
      \toprule
      \textbf{Item}          & \textbf{Qty}
      & \textbf{Reference(s)}           & \textbf{Value}                  &
      \textbf{LibPart}                          & \textbf{Footprint} \\
      \midrule
      1                      & 6                                                        & C1, C2, C5, C6, C7, C8 & 0u1                    & Device:C\_Small                  & Capacitor\_THT:C\_Disc\_D5.0mm\_W2.5mm\_P2.50mm                                                         \\
      2                      & 2                                                        & C3, C4                 & 10u                    & Device:C\_Small                  & Capacitor\_SMD:C\_1206\_3216Metric\_Pad1.42x1.75mm\_HandSolder                                          \\
      3                      & 2                                                        & D1, D2                 & LED\_RED               & Device:LED\_ALT                  & LED\_THT:LED\_D3.0mm                                                                                    \\
      4                      & 1                                                        & J1                     & Screw\_Terminal\_01x02 & Connector:Screw\_Terminal\_01x02 & TerminalBlock\_MetzConnect:TerminalBlock\_MetzConnect\_Type094\_RT03502HBLU\_1x02\_P5.00mm\_Horizontal  \\
      5                      & 1                                                        & J2                     & Barrel\_Jack           & Connector:Barrel\_Jack           & Connector\_BarrelJack:BarrelJack\_Horizontal                                                            \\
      6                      & 1                                                        & J3                     & Binding posts          & Connector\_Generic:Conn\_01x02   & psu-foot:Binding Posts                                                                                  \\
      7                      & 1                                                        & JP1                    & Min Lim                & Device:Jumper\_NO\_Small         & Connector\_PinHeader\_2.54mm:PinHeader\_1x02\_P2.54mm\_Vertical                                         \\
      8                      & 1                                                        & JP2                    & No limit               & Device:Jumper\_NO\_Small         & Connector\_PinHeader\_2.54mm:PinHeader\_1x02\_P2.54mm\_Vertical                                         \\
      9                      & 1                                                        & JP3                    & Preload                & Device:Jumper\_NO\_Small         & Connector\_PinHeader\_2.54mm:PinHeader\_1x02\_P2.54mm\_Vertical                                         \\
      10                     & 2                                                        & JP4, JP5               & Guard                  & Device:Jumper\_NO\_Small         & psu-foot:Guard\_Jumper                                                                                  \\
      11                     & 1                                                        & R1                     & 1R8                    & Device:R                         & Resistor\_SMD:R\_1206\_3216Metric\_Pad1.42x1.75mm\_HandSolder                                           \\
      12                     & 1                                                        & R2                     & 4R7                    & Device:R                         & Resistor\_SMD:R\_1206\_3216Metric\_Pad1.42x1.75mm\_HandSolder                                           \\
      13                     & 1                                                        & R3                     & 13R                    & Device:R                         & Resistor\_SMD:R\_1206\_3216Metric\_Pad1.42x1.75mm\_HandSolder                                           \\
      14                     & 1                                                        & R4                     & 27R                    & Device:R                         & Resistor\_SMD:R\_1206\_3216Metric\_Pad1.42x1.75mm\_HandSolder                                           \\
      15                     & 1                                                        & R5                     & 68R                    & Device:R                         & Resistor\_SMD:R\_1206\_3216Metric\_Pad1.42x1.75mm\_HandSolder                                           \\
      16                     & 2                                                        & R6, R14                & 100R                   & Device:R                         & Resistor\_SMD:R\_1206\_3216Metric\_Pad1.42x1.75mm\_HandSolder                                           \\
      17                     & 1                                                        & R7                     & 180R                   & Device:R                         & Resistor\_SMD:R\_1206\_3216Metric\_Pad1.42x1.75mm\_HandSolder                                           \\
      18                     & 4                                                        & R8, R10, R11, R12      & 1R0                    & Device:R                         & Resistor\_SMD:R\_1206\_3216Metric\_Pad1.42x1.75mm\_HandSolder                                           \\
      19                     & 1                                                        & R9                     & 2R2                    & Device:R                         & Resistor\_SMD:R\_1206\_3216Metric\_Pad1.42x1.75mm\_HandSolder                                           \\
      20                     & 1                                                        & R13                    & 39R                    & Device:R                         & Resistor\_SMD:R\_1206\_3216Metric\_Pad1.42x1.75mm\_HandSolder                                           \\
      21                     & 1                                                        & R15                    & 4k7                    & Device:R                         & Resistor\_THT:R\_Axial\_DIN0207\_L6.3mm\_D2.5mm\_P10.16mm\_Horizontal                                   \\
      22                     & 1                                                        & R16                    & 390R                   & Device:R                         & Resistor\_THT:R\_Axial\_DIN0207\_L6.3mm\_D2.5mm\_P10.16mm\_Horizontal                                   \\
      23                     & 1                                                        & R17                    & 1k5                    & Device:R                         & Resistor\_SMD:R\_1206\_3216Metric\_Pad1.42x1.75mm\_HandSolder                                           \\
      24                     & 1                                                        & R18                    & 1M                     & Device:R                         & Resistor\_SMD:R\_1206\_3216Metric\_Pad1.42x1.75mm\_HandSolder                                           \\
      25                     & 1                                                        & R19                    & 24k                    & Device:R                         & Resistor\_SMD:R\_1206\_3216Metric\_Pad1.42x1.75mm\_HandSolder                                           \\
      26                     & 2                                                        & R20, R26               & 1k                     & Device:R                         & Resistor\_SMD:R\_1206\_3216Metric\_Pad1.42x1.75mm\_HandSolder                                           \\
      27                     & 1                                                        & R21                    & 150k                   & Device:R                         & Resistor\_SMD:R\_1206\_3216Metric\_Pad1.42x1.75mm\_HandSolder                                           \\
      28                     & 1                                                        & R22                    & 1k                     & Device:R                         & Resistor\_THT:R\_Axial\_DIN0207\_L6.3mm\_D2.5mm\_P10.16mm\_Horizontal                                   \\
      29                     & 1                                                        & R23                    & 22R                    & Device:R                         & Resistor\_THT:R\_Axial\_DIN0207\_L6.3mm\_D2.5mm\_P10.16mm\_Horizontal                                   \\
      30                     & 2                                                        & R24, R25               & 10k                    & Device:R                         & Resistor\_SMD:R\_1206\_3216Metric\_Pad1.42x1.75mm\_HandSolder                                           \\
      31                     & 2                                                        & R27, R28               & 100R                   & Device:R                         & Resistor\_THT:R\_Axial\_DIN0207\_L6.3mm\_D2.5mm\_P10.16mm\_Horizontal                                   \\
      32                     & 1                                                        & RV1                    & 100R                   & Device:R\_POT\_US                & psu-foot:Trim\_pot\_Bourns\_TC33X-2-101E                                                                \\
      33                     & 1                                                        & RV2                    & 500k                   & Device:R\_POT\_US                & Potentiometer\_THT:Potentiometer\_Piher\_PC-16\_Single\_Horizontal                                      \\
      34                     & 1                                                        & RV3                    & 10k                    & Device:R\_POT\_US                & Potentiometer\_THT:Potentiometer\_Piher\_PC-16\_Single\_Horizontal                                      \\
      35                     & 1                                                        & RV4                    & 1k                     & Device:R\_POT\_US                & Potentiometer\_THT:Potentiometer\_Piher\_PC-16\_Single\_Horizontal                                      \\
      36                     & 1                                                        & RV5                    & 500k                   & Device:R\_POT\_US                & psu-foot:Trim\_pot\_Bourns\_TC33X-2-101E                                                                \\
      37                     & 2                                                        & SW1, SW2               & SW\_SP4T               & psu-sch:SW\_SP4T                 & psu-foot:SP4T\_CK\_SK-14D01-G-6                                                                         \\
      38                     & 1                                                        & SW3                    & Lever toggle           & Switch:SW\_SPST                  & psu-foot:SW\_SPST\_Lever\_Rubber                                                                        \\
      39                     & 1                                                        & U1                     & LM4040DBZ-2.5          & Reference\_Voltage:LM4040DBZ-2.5 & Package\_TO\_SOT\_SMD:SOT-23                                                                            \\
      40                     & 1                                                        & U2                     & LT3081                 & psu-sch:LT3081                   & Package\_SO:HTSSOP-16-1EP\_4.4x5mm\_P0.65mm\_EP3.4x5mm\_Mask3x3mm\_ThermalVias                          \\
      41                     & 1                                                        & U3                     & LM393                  & Comparator:LM393                 & Package\_SO:SOIC-8\_3.9x4.9mm\_P1.27mm                                                                  \\
      42                     & 1                                                        & U4                     & LM334M                 & Reference\_Current:LM334M        & Package\_SO:SOIC-8\_3.9x4.9mm\_P1.27mm                                                                  \\
      43                     & 2
      & U5, U6                 & LM317L\_TO92           &
      Regulator\_Linear:LM317L\_TO92   & Package\_TO\_SOT\_THT:TO-92\_Inline
      \\
      \bottomrule
  \end{tabular}}
\end{sidewaystable*}
\clearpage

\end{document}

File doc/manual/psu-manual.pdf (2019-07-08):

## Lab Power Supply Manual

Rev. B

Alex Striff

July 8, 2019

### Contents

1 Acknowledgments | 1
2 Motivation | 1
3 Safety Notice (Grounding) | 2
4 Usage Instructions | 2
4.1 Setting the output voltage | | 2
4.2 Setting the current limit | | 2
4.3 Indicator LEDs | | 2
4.4 Monitoring the output current . . . | 3
4.5 Monitoring the internal temperature 3
4.6 Disabling the internal load | | 3
4.7 Calibrating the current limit . . . . | 3
4.8 Calibrating the output error indi-
cator | | 3
5 Principles of Operation | 4
5.1 The LT3081 linear regulator . . . . | 4
5.2 The internal load | | 4
5.3 The Hot indicator circuit | | 4
5.4 The Vout error indicator circuit . . | 5
6 Schematic Diagram | 8
7 Printed Circuit Board Layers | 9
7.1 Front Copper | | 9
7.2 Back Copper | 10
7.3 Front Solder Mask | 11
7.4 Back Solder Mask | 12
7.5 Front Silk Screen | 13
7.6 Front Fabrication | 14
7.7 Plated Through-Hole Drill Map . . 15 7.8 Non-Plated Through-Hole Drill Map 16
7.9 User Comments | 17
7.10 Edge Cuts (Board Outline) . . . . 18

### List of Tables

1 | Electrical Characteristics | | 5
2 | Bill of Materials | 19

### Colophon

The schematic diagram and printed circuit board layout were both created with KiCAD. This manual was compiled using LATEX. Relatively fine (0.51 mm) lead-based solder and mildly activated rosin flux were required to solder the components to the PCB.

### 1 Acknowledgments

The creation of this lab power supply was generously funded by the Reed College Physics Department. I would like to thank Edgar Perez for his kind advice, as well as Lucas Illing for supporting this project.

### 2 Motivation

Often when working in electronics, several voltage sources are needed. In addition to a main power rail, one may need a complementary negative power rail for analog circuitry, or a different logic power supply at 3.3 V instead of 5 V. Low-impedance bias voltages are also a frequent requirement, needed for biasing BJTs, comparator inputs, and more.
For most applications, a power supply fulfilling the requirements of these applications need not be capable of supplying much more than 1 A of current, must have a stable voltage output (requiring a linear regulator), and must have a current limiting function. Additionally, it would be nice if the power supply was much smaller than a conventional 30 V, 3 A output bench power supply with a large transformer, being conveniently powered from a common wall plug, batteries, or any other DC power source at hand. I have attempted to construct such a power supply.

### 3 Safety Notice (Grounding)

Please note that the negative voltage output of the supply is directly connected to the negative voltage input to the supply. That is, the output voltage of the supply floating relative to earth ground if and only if the input voltage is floating. If you are uncertain if the supply (or any other piece of equipment) is floating, it is quick and simple to check if this is the case. Set a digital multimeter to its resistance measurement or continuity check mode. Connect one probe to the negative output of the PSU (the black five-way binding post) or to the other terminal in question, and then connect the other probe to earth ground. This can be done either by insertion in to the earth socket of a wall outlet, or by touching the outside of a BNC connector on any nearby oscilloscopes, as these are almost always earth grounded. If inserting into a wall outlet, be certain that you know which hole is which, and that you are using a multimeter approved for wall testing (most are). If the output is not floating (earth-referenced), then one must be careful to only connect oscilloscope ground leads to the negative output of the supply. Whatever the ground lead is connected to will be shorted to earth ground. If an incorrect connection is made, then connected circuit components, oscilloscopes, or computers (e.g. through USB) may be damaged. If you are uncertain, connect probes as if the circuit is not floating.
If the output is floating (or if you know which terminals are earthed and which are not), then the supply may be safely connected to other voltage sources in whatever configurations are convenient, such as in a dual-rail setup.

### 4 Usage Instructions

### 4.1 Setting the output voltage

Connect a voltmeter to the output of the supply. You may use either the binding posts or the test points labeled on the board to achieve this. Turn the PSU on and adjust the voltage using the coarse and fine adjustment knobs as needed. Note that the maximum output voltage is about 1.5 V below the input voltage.

### 4.2 Setting the current limit

To set the current limit to its minimum value, short the minimum limit jumper (labeled Min Lim, JP1). To set the current limit to higher than this value, the jumper must be open.
The current limit is set to fixed values by moving the switches on the board. The default values are 1, 2.5, 5, 10, 25, 50, and 100 mA. To set the limit to any of the upper four values, the switch for the lower values must be in its rightmost position, as indicated on the board. Alternatively, the switch section on the board may not be populated, and a 10 kΩ (preferably 10-turn) potentiometer (RV4) may be soldered in to provide a continuously variable current limit. To set the current limit to its maximum value, open the no limit jumper (labeled No Limit, JP2). To set the current limit to lower than this value, the jumper must be shorted. The maximum value is about 2.0 A in normal operation, and less when the device shuts down to prevent overheating.

### 4.3 Indicator LEDs

The power supply includes two indicator LEDs for when output voltage regulation is not guaranteed. The Hot indicator LED (D2) lights when the main regulation IC (see Section 5.1) starts to get hot (when the junction temperature is about 100 ◦C or above). This light is a warning, and the output should continue to be regulated as normal. If the IC continues to heat up (to a junction temperature of 125 ◦C), then internal protection circuitry will prevent damage and reduce the output voltage.

The Vout Error (I lim) indicator LED (D1) lights when the actual output voltage is not sufficiently close to the set output voltage. The most common cause for this is if the current limiting function is active, but internal protection circuitry or a set voltage that is too high may also cause an output error.

### 4.4 Monitoring the output current

If it is not preferred to use an ammeter to measure the output current, the Iout test point is provided for convenient measurement or external control of the load current. The signal at Iout is one volt for every ampere of output current, including the internal load (see Table 1 and Section 5.2). For example, if the supply is outputting 25 mA total, then Iout should read 25 mV.

### 4.5 Monitoring the internal tempera-

ture

For more quantitative information about the temperature of the main regulation IC (see Section 5.1) than is provided by the Hot indicator LED, the Temp test point is provided. The signal at Temp is one millivolt for every degree Celsius of junction temperature. For example, if the junction temperature of the IC is about 73 ◦C (subject to variation inside the IC), then Temp should read 73 mV.

### 4.6 Disabling the internal load

The internal load may be disabled by opening the Internal Load jumper. Note that this will increase the current limit by at most 4 mA above the current limit displayed on the switches or that previously set by RV4, if installed. For most purposes, the Internal Load jumper should be in its normal, shorted position (see Section 5.2).

### 4.7 Calibrating the current limit

The power supply requires a minimum load in order to regulate the output voltage properly. An internal load usually supplies this minimum load (see Section 5.2), but this offsets the effective current limit on the output. A trimmer potentiometer is provided to compensate for this offset. First, choose which current limit range you most value precision on, say the 10 mA range. Set the supply to a relatively low voltage, like 1 V, and place the appropriate load on the output of the supply with a potentiometer. In this case, we would adjust a potentiometer until it drew 10 mA through itself. The Vout Error (I lim) indicator LED should be off. Measuring Iout should show about 13 mV, corresponding the 10 mA external load and the (fixed) 3 mA internal load. Using a screwdriver, adjust the potentiometer (labeled Load Offset, RV1) until the output voltage is stable (no current limiting), and then carefully reverse direction and adjust until the current limit just starts to activate. This may be judged by checking the output voltage with a voltmeter, or by using the built-in indicator if it is calibrated as described in Section 4.8. If using a voltmeter (the more precise method), aim for a limit situation where the output is about 10 mV below the set (stable) voltage.

### 4.8 Calibrating the output error indi-

cator

The issues associated with creating a reliable output error indicator are discussed in Section 5.4. If necessary, a trimmer potentiometer (RV5) may be populated to correct the default setting by the resistor R21.
Attach a voltmeter to the PSU and set the output voltage to 1 V. Attach an external potentiometer to the output of the supply, valued to draw a typical current for your application. Set the PSU current limit so that increasing the load current will trigger the limit function. If the 1 V output does not demand enough current, it may be increased, but try to keep it as low as possible (see 5.4 for why). Wait until the temperature of the circuit has stabilized. Error on the side of drawing a slightly lower current than needed, depending on the sensitivity required (see below). Increase the load gradually, and watch the error indicator LED (D1).
If the default indication threshold set by R21 is not sensitive enough for your needs, solder in the 500 kΩ RV5 and try the adjustment procedure below.
If this does not work, or if the default indication did not work at all, solder in RV5 and remove R21. This provides a wider range of variation for the indication threshold, at the cost of a coarser adjustment rate.
With the potentiometer RV5 and the default resistor R21 soldered on the board or not depending on your needs, adjust the external load potentiometer until the output is 2 – 10 mV below the set voltage. If you intend to use the supply only above about 5 V, the lower the better (you may even be able to remove RV5 and wire a short across R21 for a bit more sensitivity). To complete the calibration, adjust RV5 to the barrier where D1 just barely lights, or perhaps flickers.

### 5 Principles of Operation

### 5.1 The LT3081 linear regulator

All of the regulation that the power supply provides is done by the LT3081, a rugged linear regulator IC. The regulation circuitry is depicted in Figure 1. An internal current source of 50 µA allows the set voltage to be configured with a single resistor Rset. In the power supply, Rset is determined by the two potentiometers RV2 and RV3.
If Vout < Vset, then the error amplifier will increase the base voltage of the NPN transistor until the entire Sziklai pair has Vset at its emitter. Similarly, the base voltage will be suitably reduced if Vout > Vset. In this way, the output voltage is regulated by a negative feedback loop. In practice, it may be difficult to stabilize such a circuit constructed of discrete components against oscillation. Using an integrated circuit solution such as the LT3081 allows us to have matched transistors at close to the same temperature, as well as to take advantage of the work done by previous engineers to make the output voltage stable. We simply add on some additional capacitances (C1 to C4 and C8) to improve noise characteristics, transcient performance, and stability a bit more.

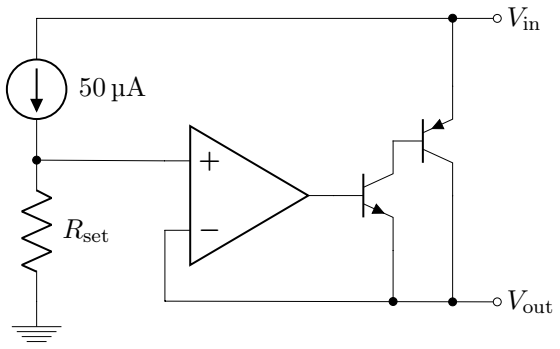
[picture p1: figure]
Vin; Rset; Vout

Figure 1: The equivalent voltage regulation circuitry inside the LT3081. The equivalent current regulation circuitry is not depicted here or in the LT3081 datasheet.

### 5.2 The internal load

Given the requirement that any circuitry used in the power supply must function consistently over the entire range of Vin, a simple resistor (as in the LT3081 datasheet) cannot be used as a means of meeting the minimum load requirement of the LT3081. Instead, the LM334 current source (U4) was used. With R23 set to 22 Ω, we expect about 3.1 mA to be sunk from the output of the power supply, which is well above the minimum load requirement of the LM3081, over temperature. Since we are manually nulling the offset due to this current, it is allowable to use a common through-hole 5 % tolerance resistor for R23, but if your application requires precise current limiting over a wide and changing range of temperatures, a 1 % or better tolerance resistor should be used for added thermal stability.

### 5.3 The Hot indicator circuit

To establish a precise voltage of 100 mV over the entire range of Vin, corresponding to a junction temperature of 100 ◦C, a 2.5 V LM4040 voltage reference (U1) and a voltage divider were used. The LM393 comparator (U3B) compares the Temp output to this reference temperature, and is configured to pull the open collector output of the comparator low if the Temp output goes above the reference. This connects the indicator LED to ground. A LM317 (U6) configured as a cur-

Table 1: Electrical characteristics. The mark indicates specifications which apply over the full operating temperature range. Otherwise, specifications are at (junction) temperatures of 25 ◦C. Note that application of negative input voltages may damage the supply. Specifically, such damage tends to disable any current limiting functionality, while maintaining the capability for voltage regulation.

Parameter | Conditions | Min | Typ | Max | Units
Input Voltage | Vin | | 5.0 | 32.0 | V
Output Voltage | Vout | Iload < Ilim, Vin < 16 V | | 0.7 | Vin − Vdo | V
Iload < Ilim, Vin ≥ 16 V | | 0.7 | 16 | V
No internal load | | 0.0 | V
Dropout Voltage | Vdo | Iload = 100 mA | 1.21 | V
Iload = 1.5 A | | 1.23 | 1.5 | V
Internal Current Limit | Imax | Vin = 5 V, Vset = 0 V, Vout = −0.1 V | | 1.5 | 2.0 | A
Iout Relative Error | Iload = 1.5 A | 0 | 6 | 11 | %
Iout Operating Range | | Vout − 40 V | Vout + 0.4 V | V
Temp Absolute Error | 0
◦C ≤ TJ ≤ 125 ◦C | -10 | 10 | µA
125 ◦C < TJ ≤ 150 ◦C | -15 | 15 | µA
Ripple Rejection | PSRR | f = 120 Hz | 75 | 90 | dB
Vripple = 0.5 Vpp, Iload = 0.1 A, | f = 10 kHz | 75 | dB
Vin = Vout(nom) + 3 V | f = 1 MHz | 20 | dB
Internal Load | Iint | | 2 | 3 | 4 | mA

rent source supplies a stable current to the LED
over the full range of Vin. Inspection of the circuit
shows that errors introduced by resistor tolerances and comparator input offset currents and voltages will result in an absolute error of at most 5

◦C.
Furthermore, the comparator operates without hysteresis, so the LED may flicker when the actual and reference temperatures coincide. For the purpose of a coarse temperature indication, these undesirable characteristics are inconsequential.

### 5.4 The Vout error indicator circuit

The general configuration of the Vout error indicator circuit is similar to that of the Hot indicator circuit, described in Section 5.3. However, the error introduced by that circuit is unacceptable for the purpose of displaying the current status of regulation. Additionally, we expect the output voltage to coincide precisely (to within a few millivolts) with the set voltage. Without any correction, the LED may reasonably indicate an error indefinitely, or at least flicker, when the output voltage is actually well-regulated.
The standard solution that one may propose is to add hysteresis (in the form of a Schmitt trigger) to the comparator. This will not work. A Schmitt trigger must have an upper trigger threshold that lies above the set voltage, but in the course of recovering from current limiting, the output voltage may never overshoot the set voltage. Thus the threshold will never be crossed, and the error indicator may remain on indefinitely. What is needed instead, is a small offset.
If the comparator recieved a set voltage that was, say, 10 mV below Vset, then the problem is solved. Hysteresis is not even needed, since most all causes for a failure in regulation will not manifest as a steady offset of 10 mV. But how can we create such a small offset over the entire range of Vout, especially when the offset is comparable in size to all of the sources of error involved? The main barriers to control that must be addressed include
- Resistor tolerances,
- Loading of input sources,
- Comparator input offset voltage,
- Comparator input bias current,
- Comparator input offset current, and
- Noise.

Since the entire point of adding the offset is to allow for errors, we can deal with the comparator input offset voltage and current by lumping in the

−

+

LM393 Vout

Roff

− | +
Iin(+)Roff
| Iin(+)

Vin

Figure 2: Introducing a small voltage offset by exploiting the input bias current of the LM393 comparator.

effect of their worst-case absolute errors with the error in regulation. This increases the minimum offset needed from that due to regulation, but only to about the 10 mV stated before. However, we cannot increase the offset too much: at an output voltage of 1.00 V, an offset of 10 mV already represents a 1 % error in indication. The aim is to keep this level of precision for set voltages from 1.00 V to 30.0 V. If better precision than about 10 % is needed below about 100 mV, the calibration procedure detailed in Section 4.8 may be done at the necessary low voltage, at the cost of less realiable indication at higher voltages of 10 V to 30 V, depending on the configuration. So how are we to obtain the offset? Since the input bias current of the comparator may introduce errors comparable to the offset, we can change perspective. The “error” that it introduces can in fact be used as the offset. The LM393 and many other common differential-input analog devices such as the LM358 have PNP darlington pair input stages. This means that any input bias current will flow out of the input terminals, conveniently allowing us to place a resistor on the noninverting input of the comparator to achieve an offset in the correct direction. Since the noninverting input is connected to the low-impedance Vout, the offset voltage introduced may be reliably predicted as Iin(+)Roff (see Figure 2). For the typical Iin(+) = 25 nA and Roff = 150 kΩ (R21), we obtain an offset of 3.8 mV. This should handle possible offsets due to comparator input offset voltage and regulation of up to 3 mV, and more offset may be provided with a potentiometer as described in Section 4.8.
But there is a problem with this circuit. Let’s

−0.5

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
−5 0 5 10 15 20 25 30 35

Offset Voltage for

Rf = 99.1 kΩ (mV)

Common Mode Voltage for Vcc = 32 V (V)

Figure 3: In the configuration of Figure 2, the offset voltage due to the input bias current of the LM358 decreases with increasing common mode voltage.

take a closer look at the input bias current. While datasheets like that for the LM393 give the input bias current at 0 V common mode voltage, we must know it for all common mode voltages up to Vin. The LM358 has a simpler input stage than the LM393, so let’s look at it instead to understand what is going on. Some quick measurements reveal that the offset voltage we are after decreases with increasing common mode voltage (Figure 3). For simplicity, we may treat this decrease as linear, as we will only be operating in the approximately linear region.
Thus our solution does not work well at high common mode voltages. We fix this by adding a high-ratio voltage divider on the other input to the comparator. Note that for a voltage divider with gain close to unity (R1 R2),

AV =

Rb
Ra + Rb

=

1
1 + Ra/Rb

≈ 1 − Ra/Rb .

Thus with 1 % resistors, we expect a relative error of about 1.4 % in Ra/Rb . For the values actually used (R17 and R18), we then obtain an absolute error of 21 µV per volt in, giving a worst case 0.6 mV error for a 30 V input. Not bad.

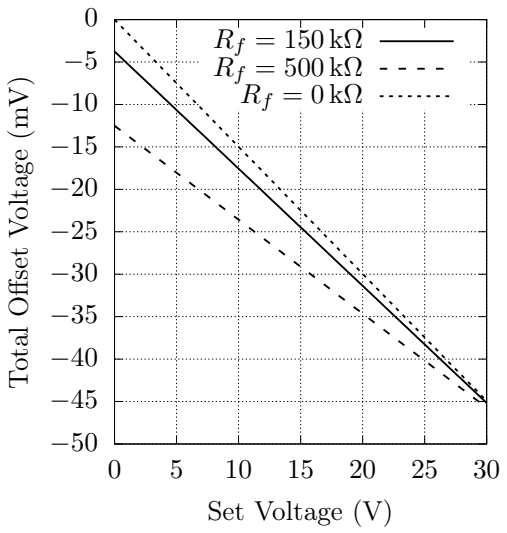
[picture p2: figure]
Total Offset Voltage (mV); Set Voltage (V)

Figure 4: The expected offsets from the full offset circuit for varying values of Rf .

Now that we know why, a quick analysis of the actual offset circuit, where we have both offset methods acting together, gives the characteristic plot of Figure 4. Values were chosen to give an increasing offset with common mode, rather than the constant offset originally discussed, for additional margin and a more understandable relative-drop trigger, rather than an offset trigger. This way, the higher voltage ranges do not seem more sensitive to loading than the lower ranges.

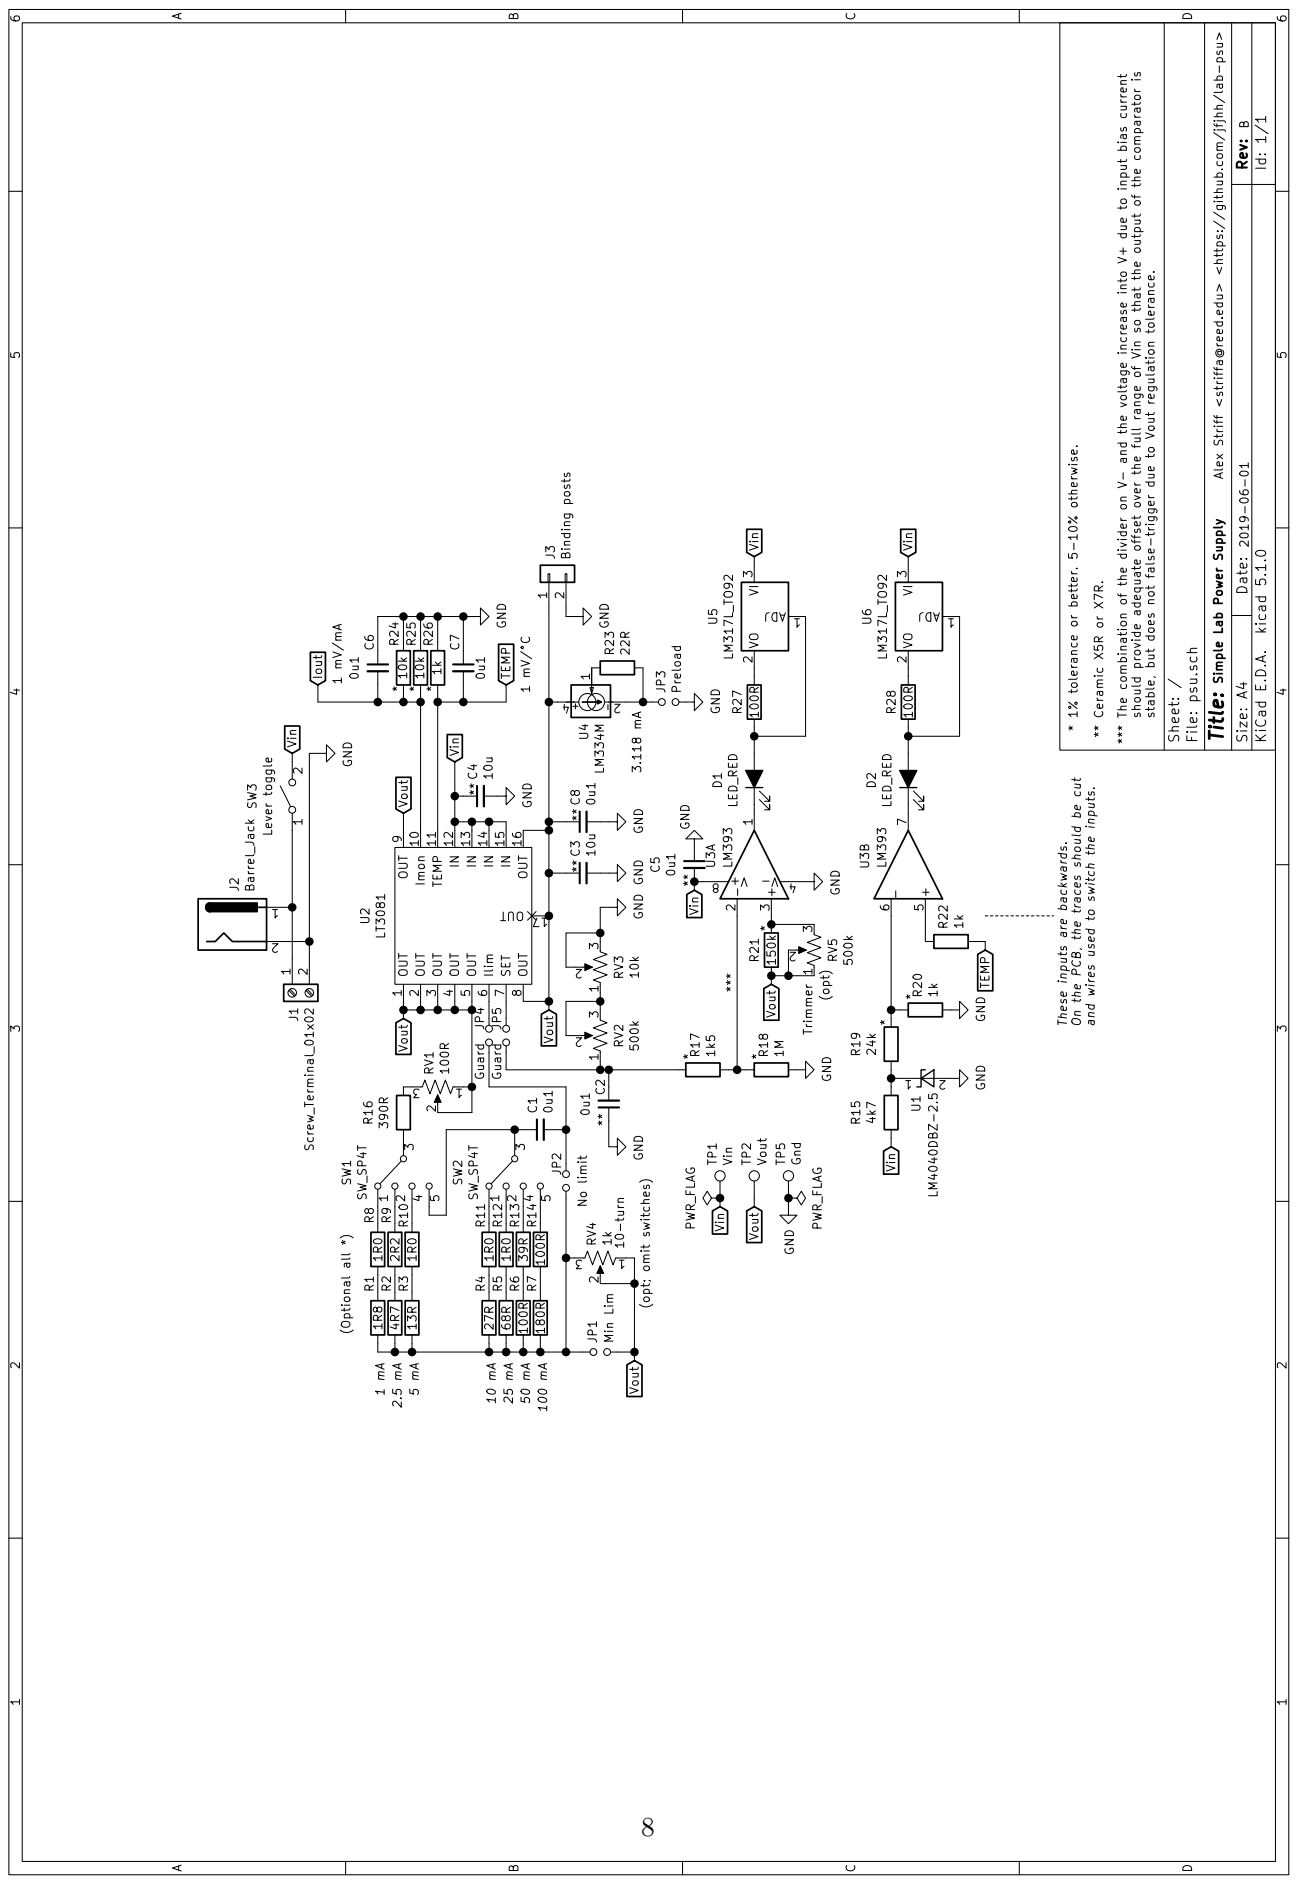
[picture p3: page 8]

D Date: KiCad E.D.A. kicad 5.1.0 Rev: Size: A4

Id: 1/1 Sheet: / File: psu.sch

Title: B 2019-06-01 Simple Lab Power Supply

Alex Striff <striffa@reed.edu> <https://github.com/jfjhh/lab-psu>

150k Vout *** The combination of the divider on V- and the voltage increase into V+ due to input bias current

should provide adequate offset over the full range of Vin so that the output of the comparator is

stable, but does not false-trigger due to Vout regulation tolerance.

J3Binding posts Vin Vout GND GND

* 1% tolerance or better. 5-10% otherwise.

Vin ADJ 1 VO 2 VI 3 U6

** 1 mV/mA ADJ 1 VO 2 VI 3 U5

Vout JP2 No limit JP3 Preload GND

Ilim 6 SET 7 OUT 8 OUT 9 U2

IN 15 OUT 16 OUT 17 OUT 2 OUT 3 OUT 4 OUT 5

These inputs are backwards. On the PCB, the traces should be cut and wires used to switch the inputs.

### 7 Printed Circuit Board Layers

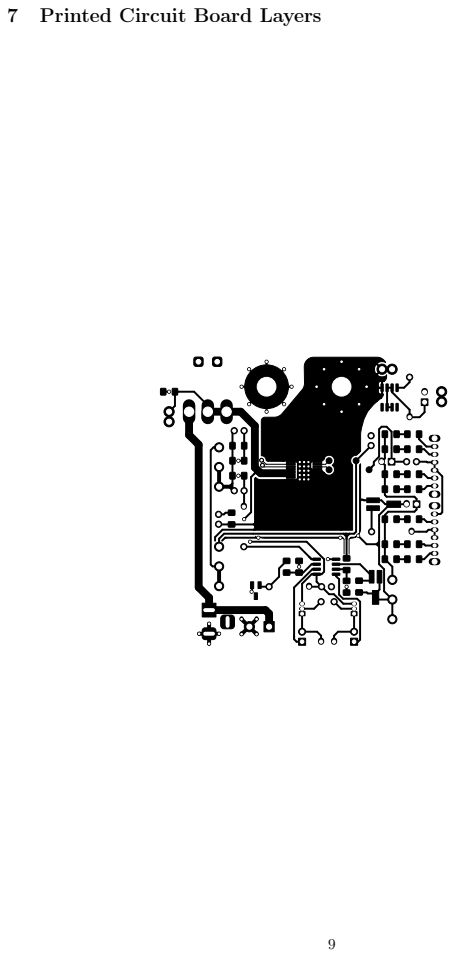
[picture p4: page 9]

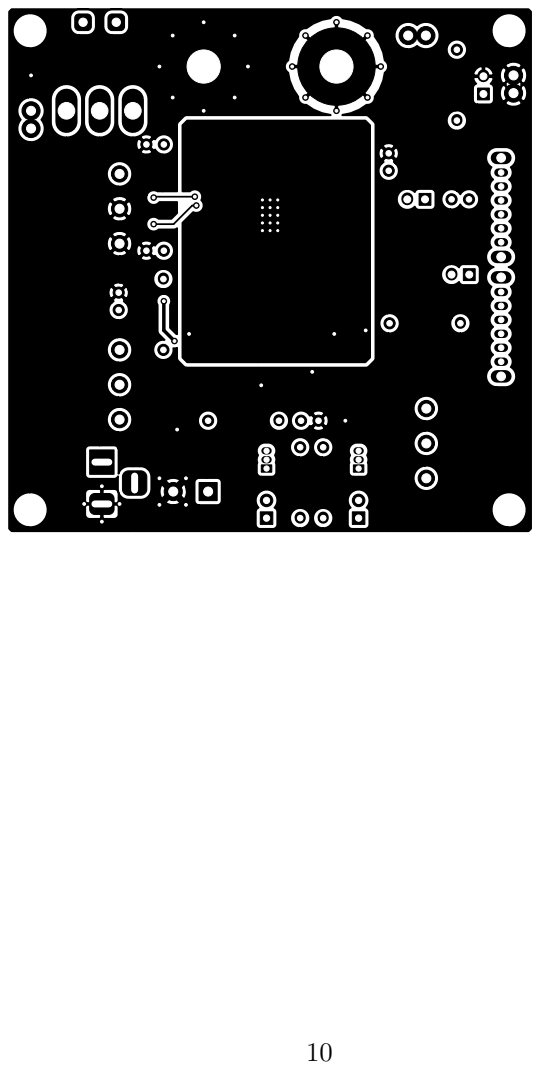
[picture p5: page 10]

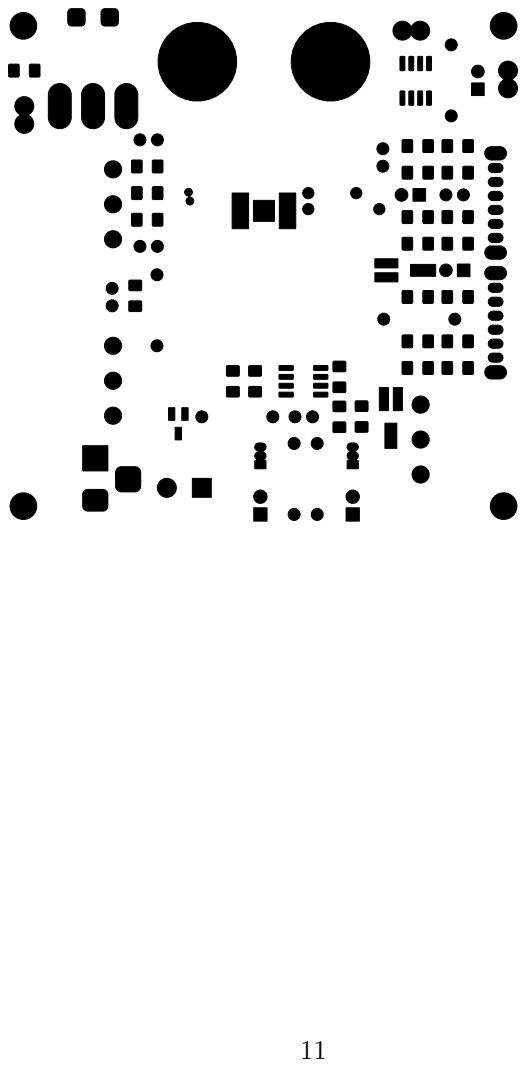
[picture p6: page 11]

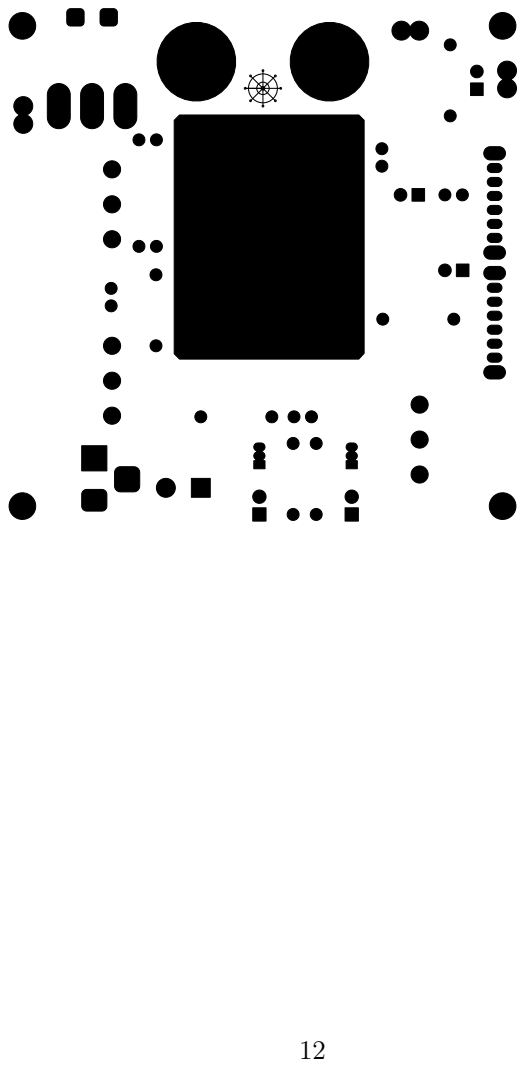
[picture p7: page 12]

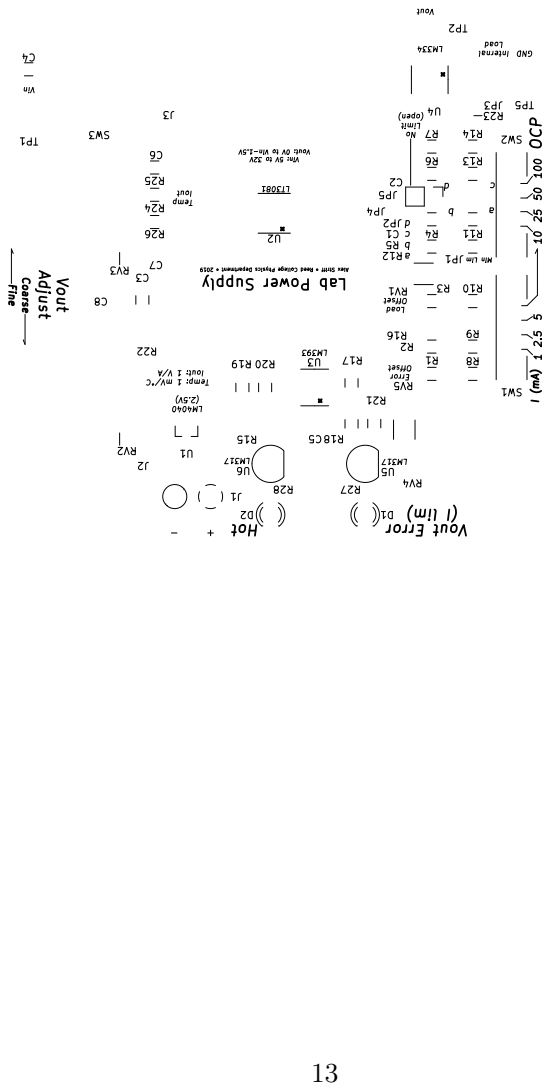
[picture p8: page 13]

Vin: 5V to 32V Vout: 0V to Vin-1.5V Alex Striff Reed College Physics Department 2019 Lab Power Supply Internal Load Iout: 1 V/A Temp: 1 mV/°C No Limit (open)Load Offset Error Offset LM317 LM317 LM393 LM4040 (2.5V) LT3081 LM334 Vout Adjust (I lim) Hot Vout Error Fine Coarse Iout Temp Min Lim Vin Vout GND OCP 100 50 25 10 5 2.5 1 I (mA) d

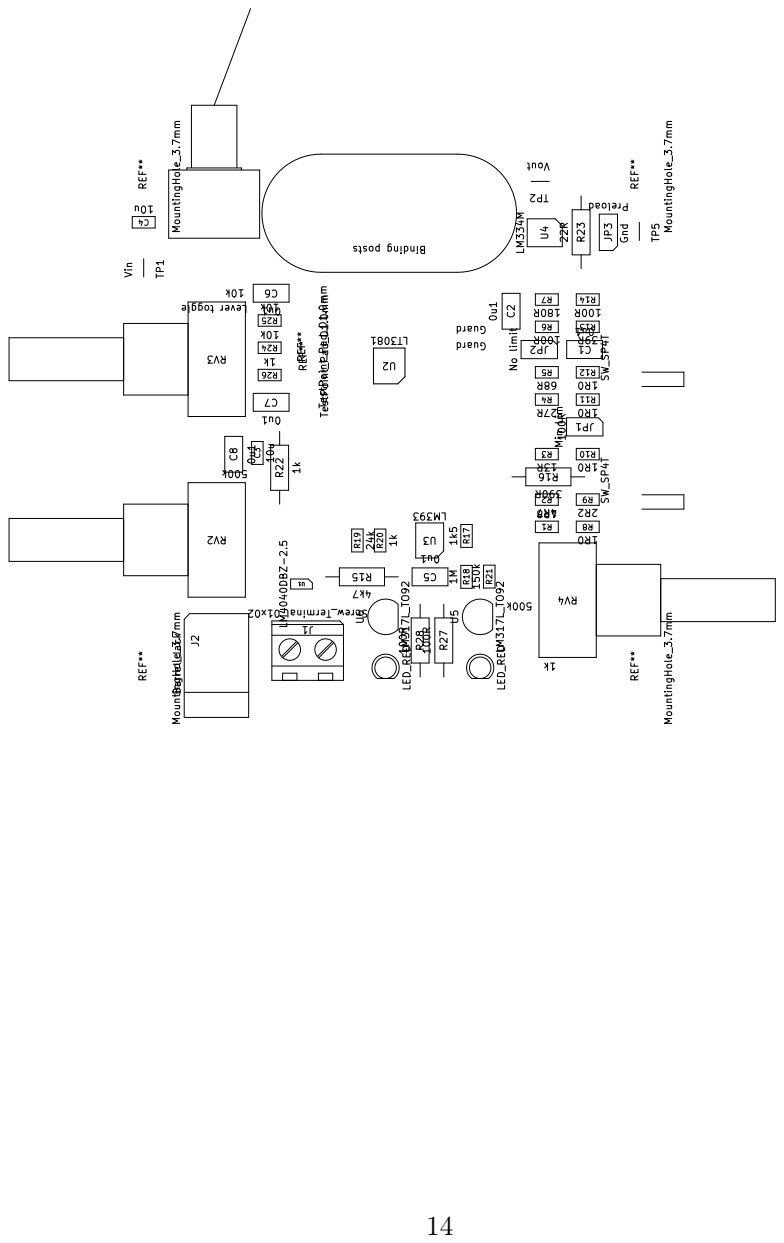
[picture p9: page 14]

100R 500k LM317L_TO92 U6 LED_RED Guard Binding posts LM317L_TO92 U5 LED_RED 27RR4 1R0 R11 68RR5 1R0 R12 Lever toggle SW_SP4T SW_SP4T 1k R26 10k R25 10k R24 150k R21 R19 24k R20 1k

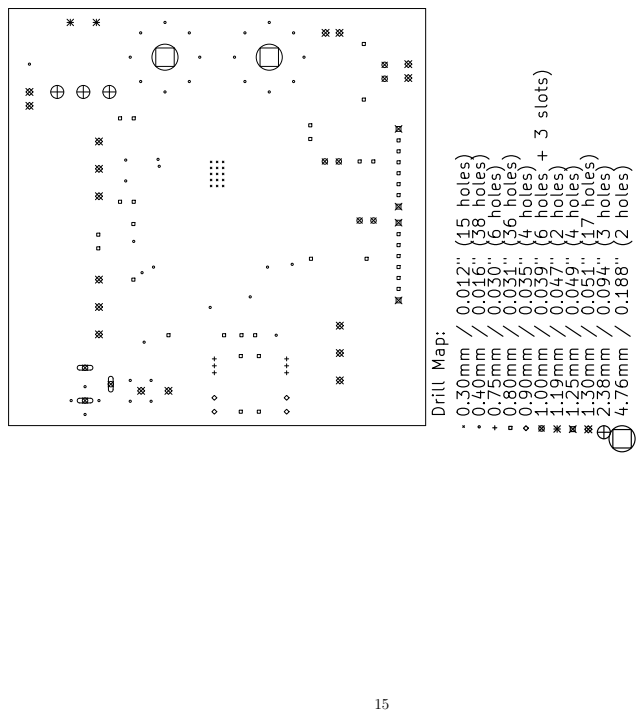
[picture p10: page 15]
Drill Map:; 0.30mm / 0.012" (15 holes); 0.40mm / 0.016" (38 holes) 0.75mm / 0.030" (6 holes); 0.80mm / 0.031" (36 holes) 0.90mm / 0.035" (4 holes); 1.00mm / 0.039" (6 holes + 3 slots); 1.19mm / 0.047" (2 holes); 1.25mm / 0.049" (4 holes); 1.30mm / 0.051" (17 holes) 2.38mm / 0.094" (3 holes); 4.76mm / 0.188" (2 holes)

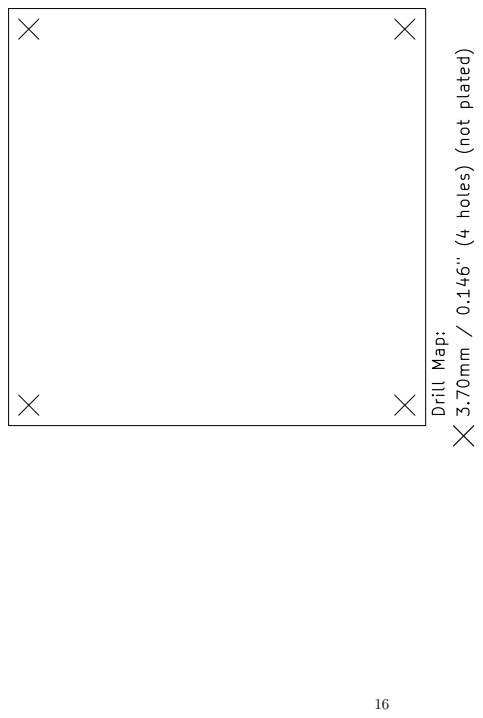
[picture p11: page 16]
Drill Map:

3.70mm / 0.146" (4 holes) (not plated)

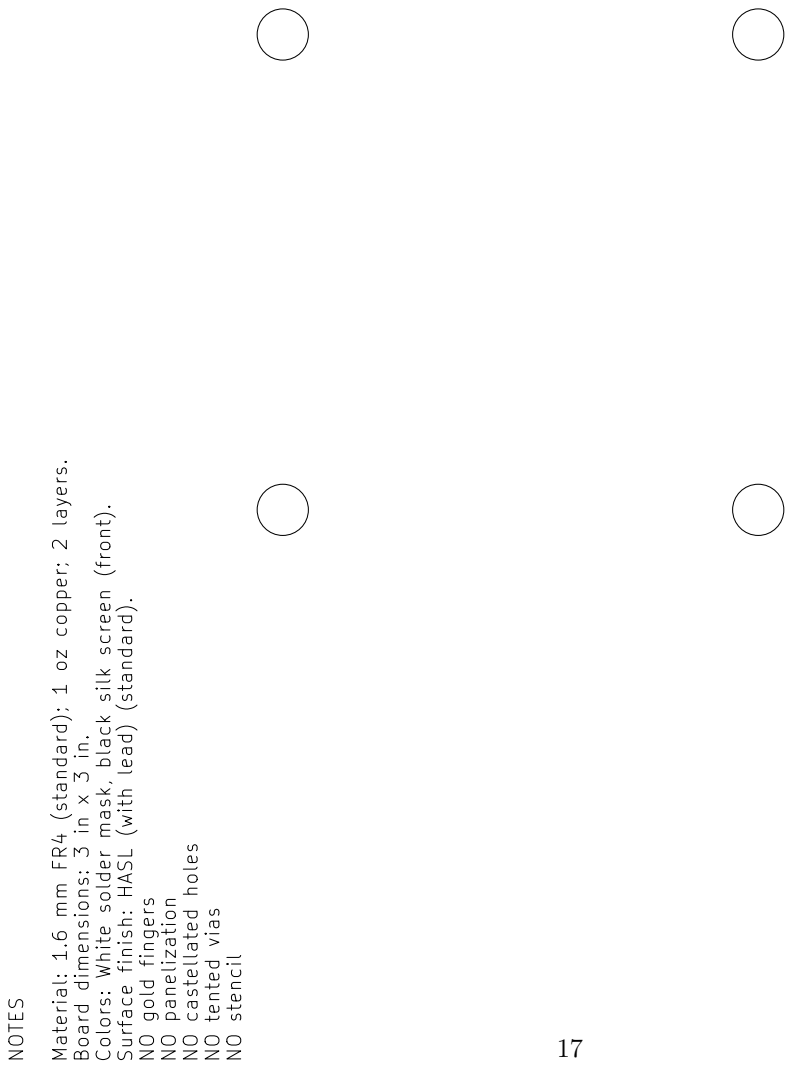
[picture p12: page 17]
NOTES; NO panelization; NO stencil

Material: 1.6 mm FR4 (standard); 1 oz copper; 2 layers.

Colors: White solder mask, black silk screen (front).

Surface finish: HASL (with lead) (standard).

Board dimensions: 3 in x 3 in.

NO castellated holes

NO gold fingers

NO tented vias

Table 2: Bill of materials with collated items. There are 60 components total.

Item Qty Reference(s) Value LibPart Footprint

1 6 C1, C2, C5, C6, C7, C8 0u1 Device:C_Small Capacitor_THT:C_Disc_D5.0mm_W2.5mm_P2.50mm

2 2 C3, C4 10u Device:C_Small Capacitor_SMD:C_1206_3216Metric_Pad1.42x1.75mm_HandSolder

3 2 D1, D2 LED_RED Device:LED_ALT LED_THT:LED_D3.0mm

4 1 J1 Screw_Terminal_01x02 Connector:Screw_Terminal_01x02 TerminalBlock_MetzConnect:TerminalBlock_MetzConnect_Type094_RT03502HBLU_1x02_P5.00mm_Horizontal

5 1 J2 Barrel_Jack Connector:Barrel_Jack Connector_BarrelJack:BarrelJack_Horizontal

6 1 J3 Binding posts Connector_Generic:Conn_01x02 psu-foot:Binding Posts

7 1 JP1 Min Lim Device:Jumper_NO_Small Connector_PinHeader_2.54mm:PinHeader_1x02_P2.54mm_Vertical

8 1 JP2 No limit Device:Jumper_NO_Small Connector_PinHeader_2.54mm:PinHeader_1x02_P2.54mm_Vertical

9 1 JP3 Preload Device:Jumper_NO_Small Connector_PinHeader_2.54mm:PinHeader_1x02_P2.54mm_Vertical

10 2 JP4, JP5 Guard Device:Jumper_NO_Small psu-foot:Guard_Jumper

11 1 R1 1R8 Device:R Resistor_SMD:R_1206_3216Metric_Pad1.42x1.75mm_HandSolder

12 1 R2 4R7 Device:R Resistor_SMD:R_1206_3216Metric_Pad1.42x1.75mm_HandSolder

13 1 R3 13R Device:R Resistor_SMD:R_1206_3216Metric_Pad1.42x1.75mm_HandSolder

14 1 R4 27R Device:R Resistor_SMD:R_1206_3216Metric_Pad1.42x1.75mm_HandSolder

15 1 R5 68R Device:R Resistor_SMD:R_1206_3216Metric_Pad1.42x1.75mm_HandSolder
16 2 R6, R14 100R Device:R Resistor_SMD:R_1206_3216Metric_Pad1.42x1.75mm_HandSolder

17 1 R7 180R Device:R Resistor_SMD:R_1206_3216Metric_Pad1.42x1.75mm_HandSolder
18 4 R8, R10, R11, R12 1R0 Device:R Resistor_SMD:R_1206_3216Metric_Pad1.42x1.75mm_HandSolder

19 1 R9 2R2 Device:R Resistor_SMD:R_1206_3216Metric_Pad1.42x1.75mm_HandSolder

20 1 R13 39R Device:R Resistor_SMD:R_1206_3216Metric_Pad1.42x1.75mm_HandSolder

21 1 R15 4k7 Device:R Resistor_THT:R_Axial_DIN0207_L6.3mm_D2.5mm_P10.16mm_Horizontal

22 1 R16 390R Device:R Resistor_THT:R_Axial_DIN0207_L6.3mm_D2.5mm_P10.16mm_Horizontal

23 1 R17 1k5 Device:R Resistor_SMD:R_1206_3216Metric_Pad1.42x1.75mm_HandSolder
24 1 R18 1M Device:R Resistor_SMD:R_1206_3216Metric_Pad1.42x1.75mm_HandSolder

25 1 R19 24k Device:R Resistor_SMD:R_1206_3216Metric_Pad1.42x1.75mm_HandSolder
26 2 R20, R26 1k Device:R Resistor_SMD:R_1206_3216Metric_Pad1.42x1.75mm_HandSolder

27 1 R21 150k Device:R Resistor_SMD:R_1206_3216Metric_Pad1.42x1.75mm_HandSolder

28 1 R22 1k Device:R Resistor_THT:R_Axial_DIN0207_L6.3mm_D2.5mm_P10.16mm_Horizontal

29 1 R23 22R Device:R Resistor_THT:R_Axial_DIN0207_L6.3mm_D2.5mm_P10.16mm_Horizontal

30 2 R24, R25 10k Device:R Resistor_SMD:R_1206_3216Metric_Pad1.42x1.75mm_HandSolder

31 2 R27, R28 100R Device:R Resistor_THT:R_Axial_DIN0207_L6.3mm_D2.5mm_P10.16mm_Horizontal

32 1 RV1 100R Device:R_POT_US psu-foot:Trim_pot_Bourns_TC33X-2-101E

33 1 RV2 500k Device:R_POT_US Potentiometer_THT:Potentiometer_Piher_PC-16_Single_Horizontal

34 1 RV3 10k Device:R_POT_US Potentiometer_THT:Potentiometer_Piher_PC-16_Single_Horizontal

35 1 RV4 1k Device:R_POT_US Potentiometer_THT:Potentiometer_Piher_PC-16_Single_Horizontal

36 1 RV5 500k Device:R_POT_US psu-foot:Trim_pot_Bourns_TC33X-2-101E

37 2 SW1, SW2 SW_SP4T psu-sch:SW_SP4T psu-foot:SP4T_CK_SK-14D01-G-6

38 1 SW3 Lever toggle Switch:SW_SPST psu-foot:SW_SPST_Lever_Rubber
39 1 U1 LM4040DBZ-2.5 Reference_Voltage:LM4040DBZ-2.5 Package_TO_SOT_SMD:SOT-23

40 1 U2 LT3081 psu-sch:LT3081 Package_SO:HTSSOP-16-1EP_4.4x5mm_P0.65mm_EP3.4x5mm_Mask3x3mm_ThermalVias

41 1 U3 LM393 Comparator:LM393 Package_SO:SOIC-8_3.9x4.9mm_P1.27mm
42 1 U4 LM334M Reference_Current:LM334M Package_SO:SOIC-8_3.9x4.9mm_P1.27mm
43 2 U5, U6 LM317L_TO92 Regulator_Linear:LM317L_TO92 Package_TO_SOT_THT:TO-92_Inline

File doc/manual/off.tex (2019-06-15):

% GNUPLOT: LaTeX picture with Postscript
\begingroup
  \makeatletter
  \providecommand\color[2][]{%
    \GenericError{(gnuplot) \space\space\space\@spaces}{%
      Package color not loaded in conjunction with
      terminal option `colourtext'%
    }{See the gnuplot documentation for explanation.%
    }{Either use 'blacktext' in gnuplot or load the package
      color.sty in LaTeX.}%
    \renewcommand\color[2][]{}%
  }%
  \providecommand\includegraphics[2][]{%
    \GenericError{(gnuplot) \space\space\space\@spaces}{%
      Package graphicx or graphics not loaded%
    }{See the gnuplot documentation for explanation.%
    }{The gnuplot epslatex terminal needs graphicx.sty or graphics.sty.}%
    \renewcommand\includegraphics[2][]{}%
  }%
  \providecommand\rotatebox[2]{#2}%
  \@ifundefined{ifGPcolor}{%
    \newif\ifGPcolor
    \GPcolorfalse
  }{}%
  \@ifundefined{ifGPblacktext}{%
    \newif\ifGPblacktext
    \GPblacktexttrue
  }{}%
  % define a \g@addto@macro without @ in the name:
  \let\gplgaddtomacro\g@addto@macro
  % define empty templates for all commands taking text:
  \gdef\gplbacktext{}%
  \gdef\gplfronttext{}%
  \makeatother
  \ifGPblacktext
    % no textcolor at all
    \def\colorrgb#1{}%
    \def\colorgray#1{}%
  \else
    % gray or color?
    \ifGPcolor
      \def\colorrgb#1{\color[rgb]{#1}}%
      \def\colorgray#1{\color[gray]{#1}}%
      \expandafter\def\csname LTw\endcsname{\color{white}}%
      \expandafter\def\csname LTb\endcsname{\color{black}}%
      \expandafter\def\csname LTa\endcsname{\color{black}}%
      \expandafter\def\csname LT0\endcsname{\color[rgb]{1,0,0}}%
      \expandafter\def\csname LT1\endcsname{\color[rgb]{0,1,0}}%
      \expandafter\def\csname LT2\endcsname{\color[rgb]{0,0,1}}%
      \expandafter\def\csname LT3\endcsname{\color[rgb]{1,0,1}}%
      \expandafter\def\csname LT4\endcsname{\color[rgb]{0,1,1}}%
      \expandafter\def\csname LT5\endcsname{\color[rgb]{1,1,0}}%
      \expandafter\def\csname LT6\endcsname{\color[rgb]{0,0,0}}%
      \expandafter\def\csname LT7\endcsname{\color[rgb]{1,0.3,0}}%
      \expandafter\def\csname LT8\endcsname{\color[rgb]{0.5,0.5,0.5}}%
    \else
      % gray
      \def\colorrgb#1{\color{black}}%
      \def\colorgray#1{\color[gray]{#1}}%
      \expandafter\def\csname LTw\endcsname{\color{white}}%
      \expandafter\def\csname LTb\endcsname{\color{black}}%
      \expandafter\def\csname LTa\endcsname{\color{black}}%
      \expandafter\def\csname LT0\endcsname{\color{black}}%
      \expandafter\def\csname LT1\endcsname{\color{black}}%
      \expandafter\def\csname LT2\endcsname{\color{black}}%
      \expandafter\def\csname LT3\endcsname{\color{black}}%
      \expandafter\def\csname LT4\endcsname{\color{black}}%
      \expandafter\def\csname LT5\endcsname{\color{black}}%
      \expandafter\def\csname LT6\endcsname{\color{black}}%
      \expandafter\def\csname LT7\endcsname{\color{black}}%
      \expandafter\def\csname LT8\endcsname{\color{black}}%
    \fi
  \fi
    \setlength{\unitlength}{0.0500bp}%
    \ifx\gptboxheight\undefined%
      \newlength{\gptboxheight}%
      \newlength{\gptboxwidth}%
      \newsavebox{\gptboxtext}%
    \fi%
    \setlength{\fboxrule}{0.5pt}%
    \setlength{\fboxsep}{1pt}%
\begin{picture}(4320.00,4320.00)%
    \gplgaddtomacro\gplbacktext{%
      \csname LTb\endcsname%%
      \put(814,704){\makebox(0,0)[r]{\strut{}$-50$}}%
      \csname LTb\endcsname%%
      \put(814,1044){\makebox(0,0)[r]{\strut{}$-45$}}%
      \csname LTb\endcsname%%
      \put(814,1383){\makebox(0,0)[r]{\strut{}$-40$}}%
      \csname LTb\endcsname%%
      \put(814,1723){\makebox(0,0)[r]{\strut{}$-35$}}%
      \csname LTb\endcsname%%
      \put(814,2062){\makebox(0,0)[r]{\strut{}$-30$}}%
      \csname LTb\endcsname%%
      \put(814,2402){\makebox(0,0)[r]{\strut{}$-25$}}%
      \csname LTb\endcsname%%
      \put(814,2741){\makebox(0,0)[r]{\strut{}$-20$}}%
      \csname LTb\endcsname%%
      \put(814,3081){\makebox(0,0)[r]{\strut{}$-15$}}%
      \csname LTb\endcsname%%
      \put(814,3420){\makebox(0,0)[r]{\strut{}$-10$}}%
      \csname LTb\endcsname%%
      \put(814,3760){\makebox(0,0)[r]{\strut{}$-5$}}%
      \csname LTb\endcsname%%
      \put(814,4099){\makebox(0,0)[r]{\strut{}$0$}}%
      \csname LTb\endcsname%%
      \put(946,484){\makebox(0,0){\strut{}$0$}}%
      \csname LTb\endcsname%%
      \put(1442,484){\makebox(0,0){\strut{}$5$}}%
      \csname LTb\endcsname%%
      \put(1938,484){\makebox(0,0){\strut{}$10$}}%
      \csname LTb\endcsname%%
      \put(2435,484){\makebox(0,0){\strut{}$15$}}%
      \csname LTb\endcsname%%
      \put(2931,484){\makebox(0,0){\strut{}$20$}}%
      \csname LTb\endcsname%%
      \put(3427,484){\makebox(0,0){\strut{}$25$}}%
      \csname LTb\endcsname%%
      \put(3923,484){\makebox(0,0){\strut{}$30$}}%
    }%
    \gplgaddtomacro\gplfronttext{%
      \csname LTb\endcsname%%
      \put(198,2401){\rotatebox{-270}{\makebox(0,0){\strut{}Total Offset Voltage (\si{\mV})}}}%
      \put(2434,154){\makebox(0,0){\strut{}Set Voltage (V)}}%
      \put(2936,3926){\makebox(0,0)[r]{\strut{}$R_f = \SI{150}{\kohm}$}}%
      \put(2936,3706){\makebox(0,0)[r]{\strut{}$R_f = \SI{500}{\kohm}$}}%
      \put(2936,3486){\makebox(0,0)[r]{\strut{}$R_f = \SI{0}{\kohm}$}}%
    }%
    \gplbacktext
    \put(0,0){}%
    \gplfronttext
  \end{picture}%
\endgroup

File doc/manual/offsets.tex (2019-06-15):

% GNUPLOT: LaTeX picture with Postscript
\begingroup
  \makeatletter
  \providecommand\color[2][]{%
    \GenericError{(gnuplot) \space\space\space\@spaces}{%
      Package color not loaded in conjunction with
      terminal option `colourtext'%
    }{See the gnuplot documentation for explanation.%
    }{Either use 'blacktext' in gnuplot or load the package
      color.sty in LaTeX.}%
    \renewcommand\color[2][]{}%
  }%
  \providecommand\includegraphics[2][]{%
    \GenericError{(gnuplot) \space\space\space\@spaces}{%
      Package graphicx or graphics not loaded%
    }{See the gnuplot documentation for explanation.%
    }{The gnuplot epslatex terminal needs graphicx.sty or graphics.sty.}%
    \renewcommand\includegraphics[2][]{}%
  }%
  \providecommand\rotatebox[2]{#2}%
  \@ifundefined{ifGPcolor}{%
    \newif\ifGPcolor
    \GPcolorfalse
  }{}%
  \@ifundefined{ifGPblacktext}{%
    \newif\ifGPblacktext
    \GPblacktexttrue
  }{}%
  % define a \g@addto@macro without @ in the name:
  \let\gplgaddtomacro\g@addto@macro
  % define empty templates for all commands taking text:
  \gdef\gplbacktext{}%
  \gdef\gplfronttext{}%
  \makeatother
  \ifGPblacktext
    % no textcolor at all
    \def\colorrgb#1{}%
    \def\colorgray#1{}%
  \else
    % gray or color?
    \ifGPcolor
      \def\colorrgb#1{\color[rgb]{#1}}%
      \def\colorgray#1{\color[gray]{#1}}%
      \expandafter\def\csname LTw\endcsname{\color{white}}%
      \expandafter\def\csname LTb\endcsname{\color{black}}%
      \expandafter\def\csname LTa\endcsname{\color{black}}%
      \expandafter\def\csname LT0\endcsname{\color[rgb]{1,0,0}}%
      \expandafter\def\csname LT1\endcsname{\color[rgb]{0,1,0}}%
      \expandafter\def\csname LT2\endcsname{\color[rgb]{0,0,1}}%
      \expandafter\def\csname LT3\endcsname{\color[rgb]{1,0,1}}%
      \expandafter\def\csname LT4\endcsname{\color[rgb]{0,1,1}}%
      \expandafter\def\csname LT5\endcsname{\color[rgb]{1,1,0}}%
      \expandafter\def\csname LT6\endcsname{\color[rgb]{0,0,0}}%
      \expandafter\def\csname LT7\endcsname{\color[rgb]{1,0.3,0}}%
      \expandafter\def\csname LT8\endcsname{\color[rgb]{0.5,0.5,0.5}}%
    \else
      % gray
      \def\colorrgb#1{\color{black}}%
      \def\colorgray#1{\color[gray]{#1}}%
      \expandafter\def\csname LTw\endcsname{\color{white}}%
      \expandafter\def\csname LTb\endcsname{\color{black}}%
      \expandafter\def\csname LTa\endcsname{\color{black}}%
      \expandafter\def\csname LT0\endcsname{\color{black}}%
      \expandafter\def\csname LT1\endcsname{\color{black}}%
      \expandafter\def\csname LT2\endcsname{\color{black}}%
      \expandafter\def\csname LT3\endcsname{\color{black}}%
      \expandafter\def\csname LT4\endcsname{\color{black}}%
      \expandafter\def\csname LT5\endcsname{\color{black}}%
      \expandafter\def\csname LT6\endcsname{\color{black}}%
      \expandafter\def\csname LT7\endcsname{\color{black}}%
      \expandafter\def\csname LT8\endcsname{\color{black}}%
    \fi
  \fi
    \setlength{\unitlength}{0.0500bp}%
    \ifx\gptboxheight\undefined%
      \newlength{\gptboxheight}%
      \newlength{\gptboxwidth}%
      \newsavebox{\gptboxtext}%
    \fi%
    \setlength{\fboxrule}{0.5pt}%
    \setlength{\fboxsep}{1pt}%
\begin{picture}(4320.00,4320.00)%
    \gplgaddtomacro\gplbacktext{%
      \csname LTb\endcsname%%
      \put(946,704){\makebox(0,0)[r]{\strut{}$-0.5$}}%
      \csname LTb\endcsname%%
      \put(946,1044){\makebox(0,0)[r]{\strut{}$0$}}%
      \csname LTb\endcsname%%
      \put(946,1383){\makebox(0,0)[r]{\strut{}$0.5$}}%
      \csname LTb\endcsname%%
      \put(946,1723){\makebox(0,0)[r]{\strut{}$1$}}%
      \csname LTb\endcsname%%
      \put(946,2062){\makebox(0,0)[r]{\strut{}$1.5$}}%
      \csname LTb\endcsname%%
      \put(946,2402){\makebox(0,0)[r]{\strut{}$2$}}%
      \csname LTb\endcsname%%
      \put(946,2741){\makebox(0,0)[r]{\strut{}$2.5$}}%
      \csname LTb\endcsname%%
      \put(946,3081){\makebox(0,0)[r]{\strut{}$3$}}%
      \csname LTb\endcsname%%
      \put(946,3420){\makebox(0,0)[r]{\strut{}$3.5$}}%
      \csname LTb\endcsname%%
      \put(946,3760){\makebox(0,0)[r]{\strut{}$4$}}%
      \csname LTb\endcsname%%
      \put(946,4099){\makebox(0,0)[r]{\strut{}$4.5$}}%
      \csname LTb\endcsname%%
      \put(1078,484){\makebox(0,0){\strut{}$-5$}}%
      \csname LTb\endcsname%%
      \put(1434,484){\makebox(0,0){\strut{}$0$}}%
      \csname LTb\endcsname%%
      \put(1789,484){\makebox(0,0){\strut{}$5$}}%
      \csname LTb\endcsname%%
      \put(2145,484){\makebox(0,0){\strut{}$10$}}%
      \csname LTb\endcsname%%
      \put(2501,484){\makebox(0,0){\strut{}$15$}}%
      \csname LTb\endcsname%%
      \put(2856,484){\makebox(0,0){\strut{}$20$}}%
      \csname LTb\endcsname%%
      \put(3212,484){\makebox(0,0){\strut{}$25$}}%
      \csname LTb\endcsname%%
      \put(3567,484){\makebox(0,0){\strut{}$30$}}%
      \csname LTb\endcsname%%
      \put(3923,484){\makebox(0,0){\strut{}$35$}}%
    }%
    \gplgaddtomacro\gplfronttext{%
      \csname LTb\endcsname%%
      \put(198,2401){\rotatebox{-270}{\makebox(0,0){\strut{}Offset Voltage for $R_f = \SI{99.1}{\kohm}$ (\si{\mV})}}}%
      \put(2500,154){\makebox(0,0){\strut{}Common Mode Voltage for $V_{cc} = \SI{32}{\V}$ (\si{V})}}%
    }%
    \gplbacktext
    \put(0,0){}%
    \gplfronttext
  \end{picture}%
\endgroup

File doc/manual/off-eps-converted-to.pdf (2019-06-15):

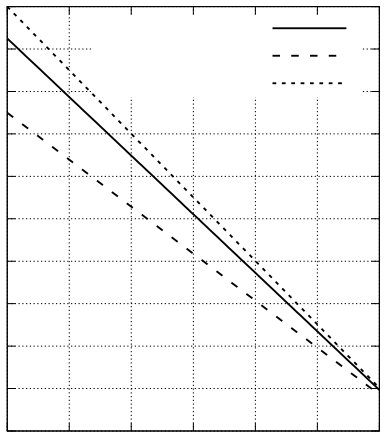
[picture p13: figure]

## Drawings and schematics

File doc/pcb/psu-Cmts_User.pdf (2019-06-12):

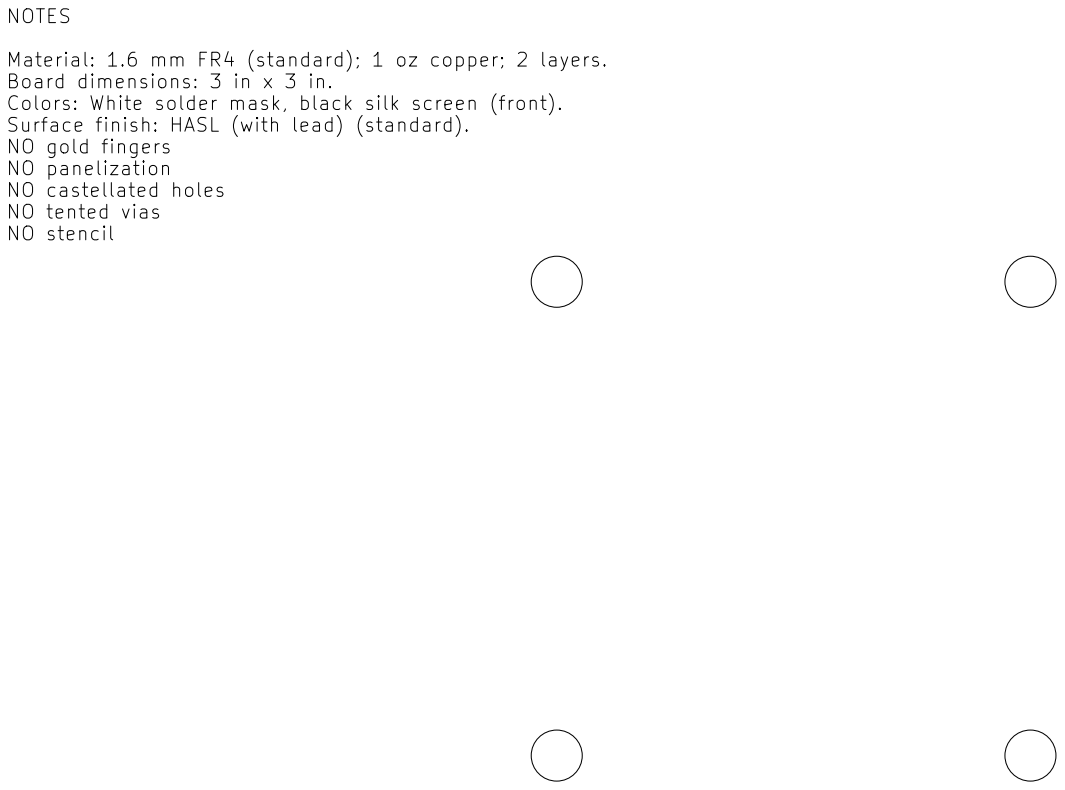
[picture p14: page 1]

NOTES
Material: 1.6 mm FR4 (standard); 1 oz copper; 2 layers.
Board dimensions: 3 in x 3 in.
Colors: White solder mask, black silk screen (front).
Surface finish: HASL (with lead) (standard).
NO gold fingers
NO panelization
NO castellated holes
NO tented vias
NO stencil

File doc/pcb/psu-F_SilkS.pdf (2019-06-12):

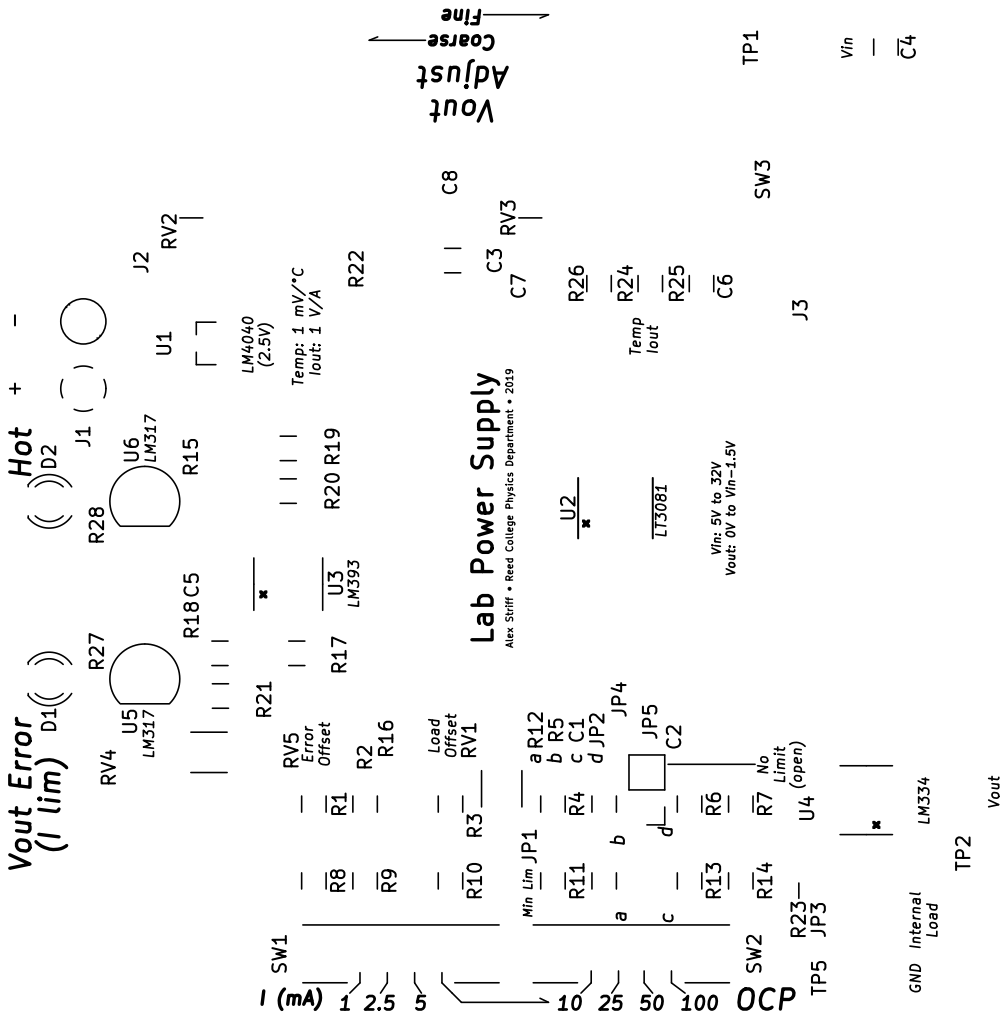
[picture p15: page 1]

Vin: 5V to 32V Vout: 0V to Vin-1.5V Lab Power Supply Alex Striff Reed College Physics Department 2019 Internal Load Iout: 1 V/A Temp: 1 mV/°C No Limit (open)Load Offset Error Offset LM317 LM317 LM393 LM4040 (2.5V) LT3081 LM334 Vout Adjust (I lim) Vout Error Hot Fine Coarse Temp Iout Min Lim Vin Vout GND I (mA) 1 2.5 5 10 25 50 100 OCP abcd d c b a - + JP5 R27 R28 R22 R15 R16 JP1 TP1 TP5 R23 JP3 TP2 C7 C6 C8 C5 C1 C2 J1 J2 U4 RV3 RV2 RV4 U3 U1 U2 RV1 RV5 U6 D1JP4 J3 U5 D2 R4 R11 R12 R5 SW3 SW1 SW2 R26 R24 R25 R21 R20 R19 R18 R17 R8 R9 R10 R13 R14 R6 R7 R3 R2 R1 JP2 C4 C3

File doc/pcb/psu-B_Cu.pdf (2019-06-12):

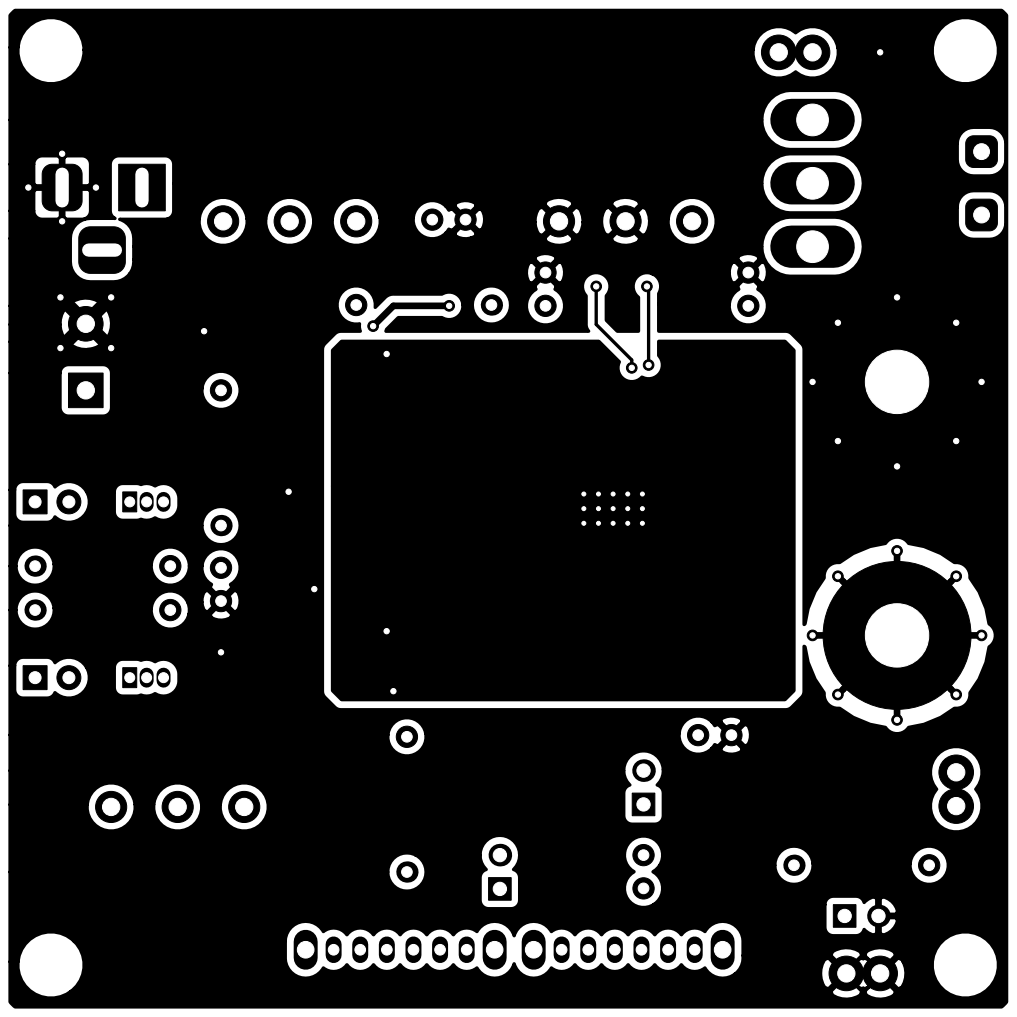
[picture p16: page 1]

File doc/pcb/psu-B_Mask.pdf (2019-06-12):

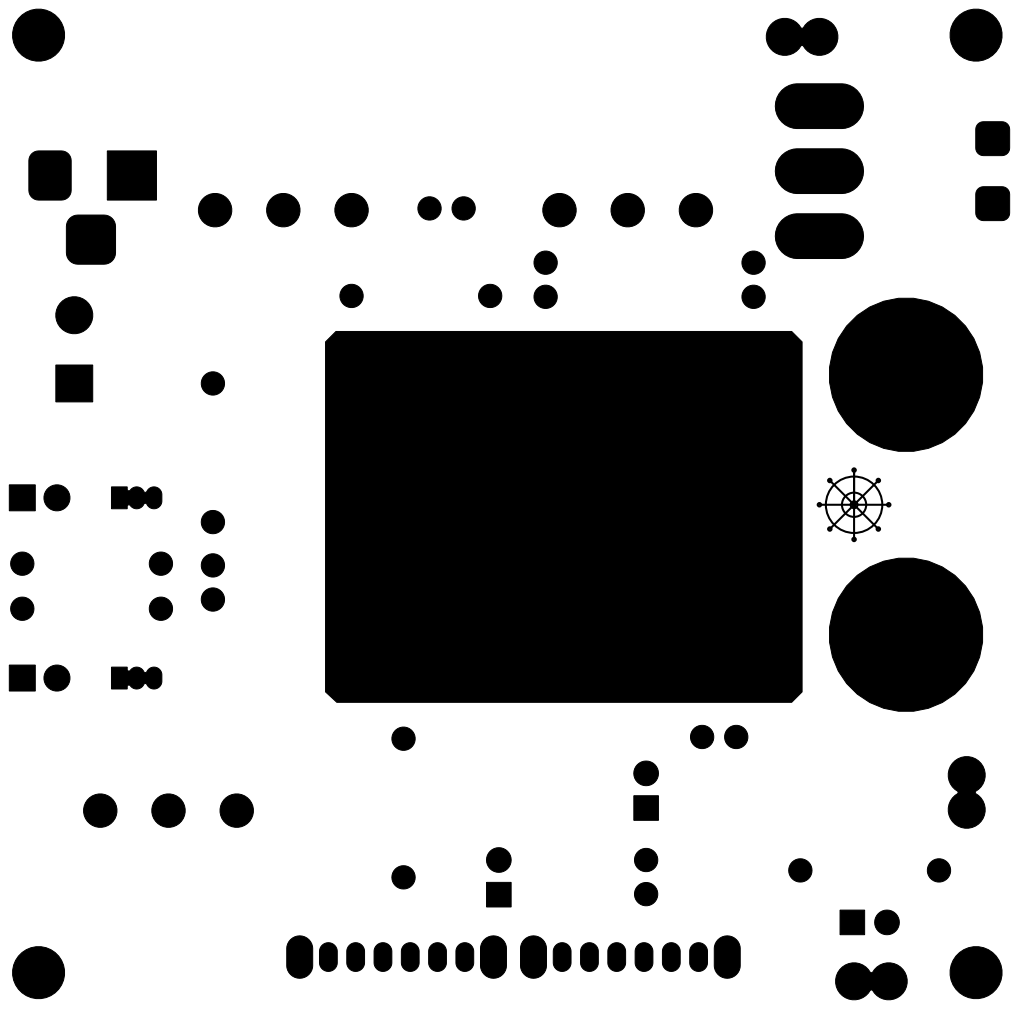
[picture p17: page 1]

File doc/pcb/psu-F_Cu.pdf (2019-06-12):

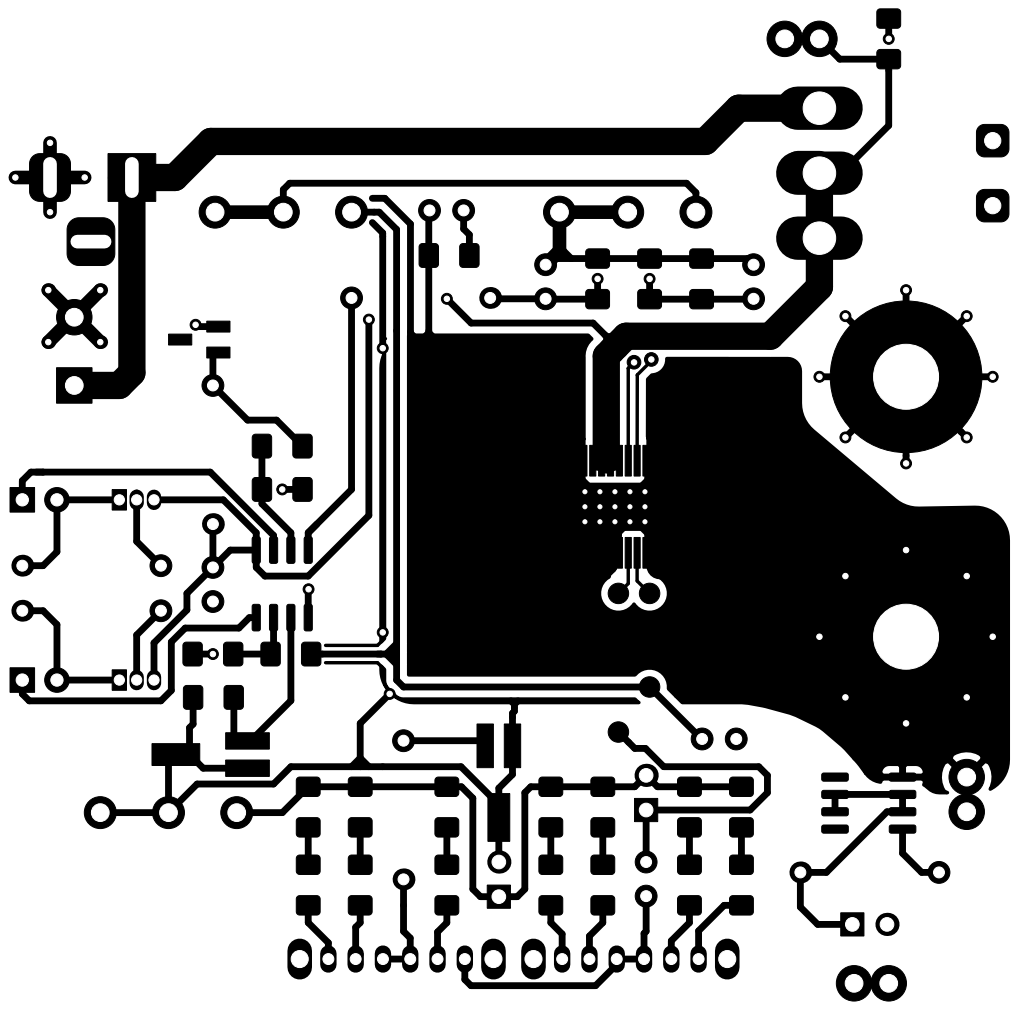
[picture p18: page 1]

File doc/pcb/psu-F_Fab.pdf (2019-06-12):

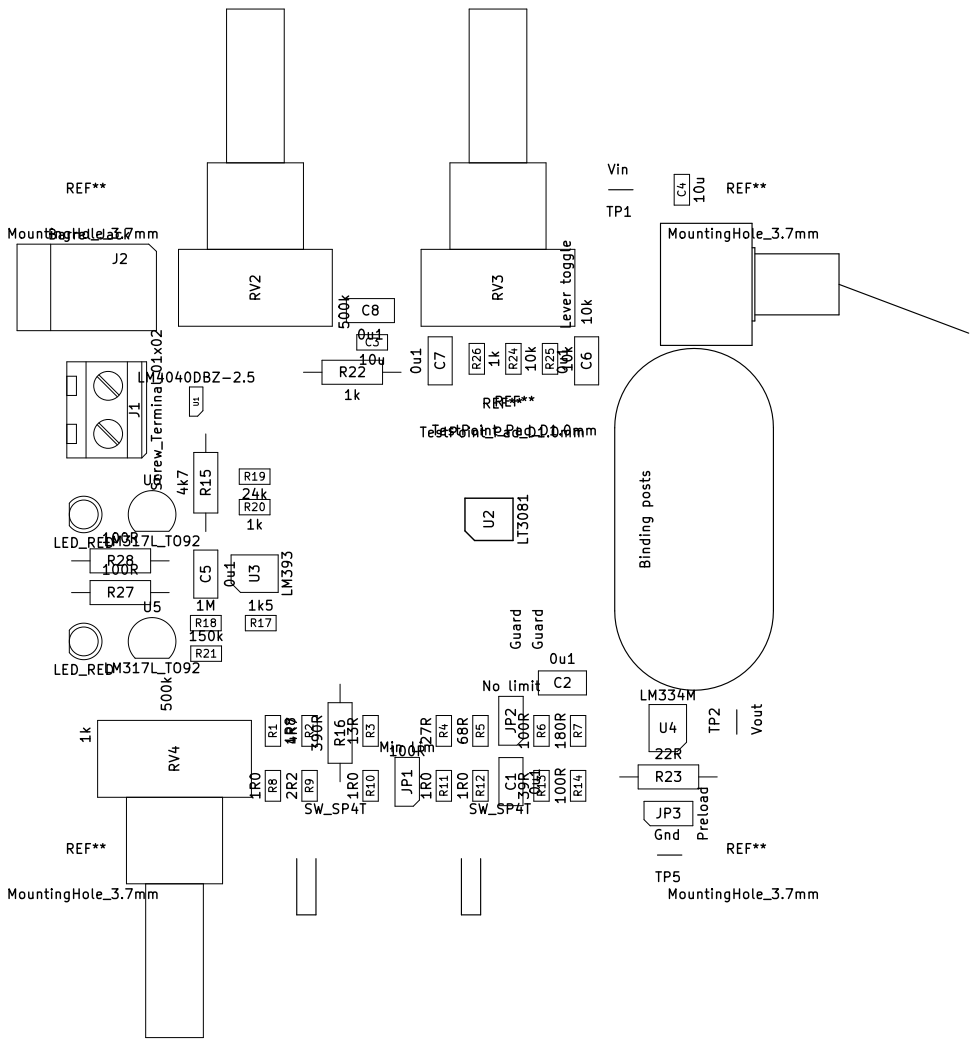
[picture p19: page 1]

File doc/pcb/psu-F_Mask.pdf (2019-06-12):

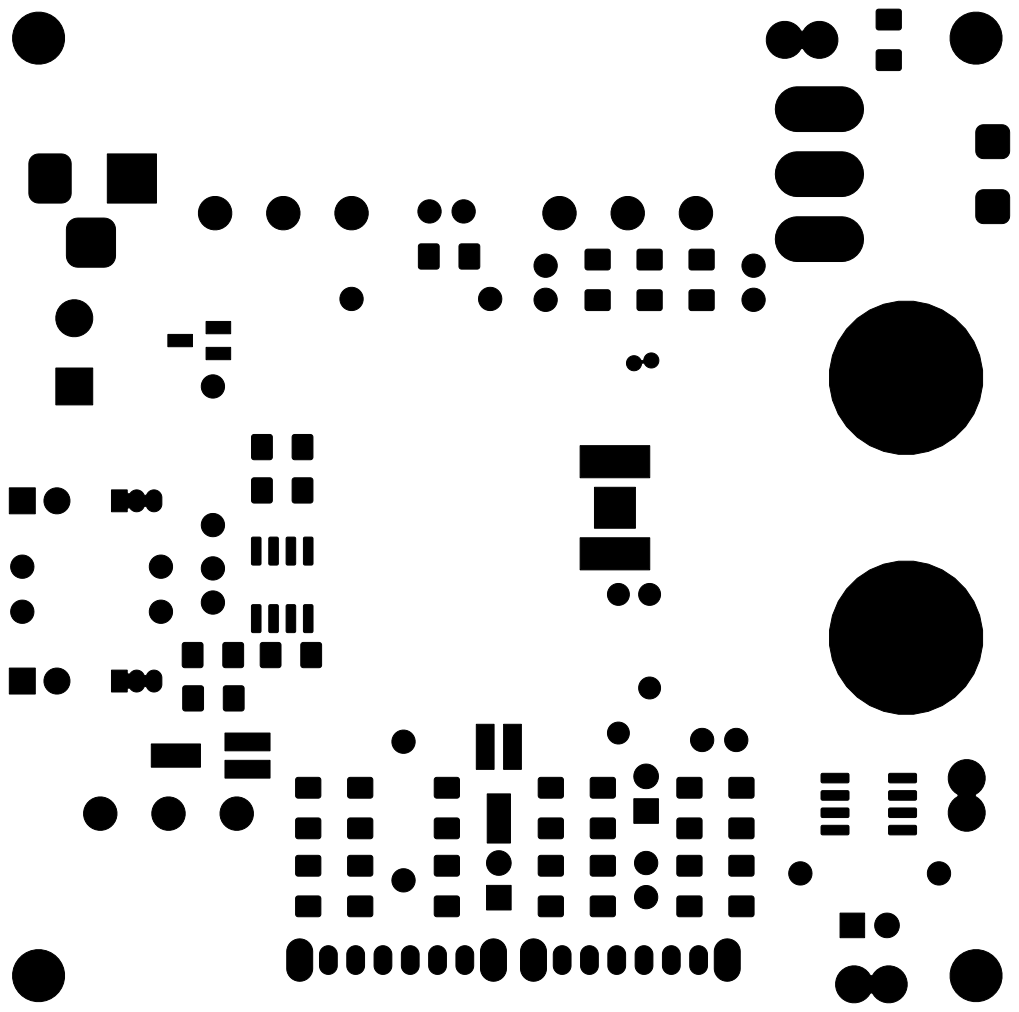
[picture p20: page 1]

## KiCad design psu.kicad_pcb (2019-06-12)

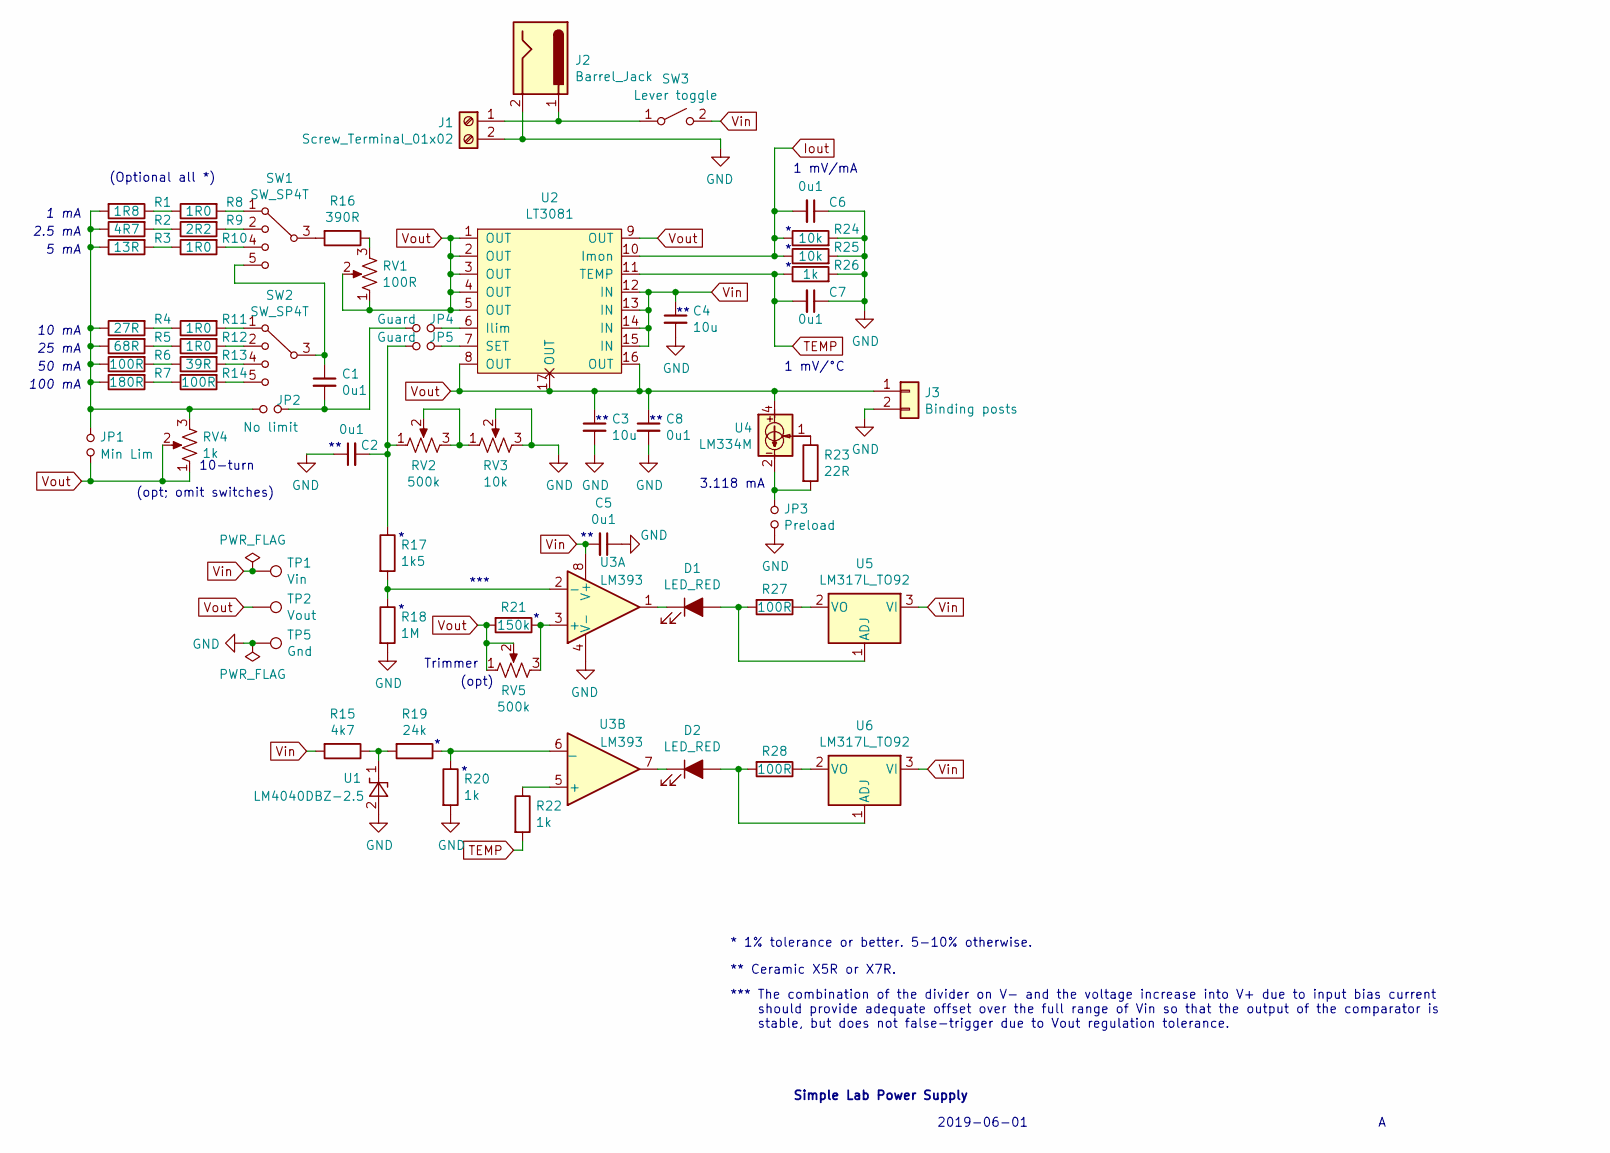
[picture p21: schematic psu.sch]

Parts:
C1, C2, C5, C6, C7, C8: 0u1; C_Disc_D5.0mm_W2.5mm_P2.50mm
C3, C4: 10u; C_1206_3216Metric_Pad1.42x1.75mm_HandSolder
D1, D2: LED_RED; LED_D3.0mm
J1: Screw_Terminal_01x02; TerminalBlock_MetzConnect_Type094_RT03502HBLU_1x02_P5.00mm_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
J2: Barrel_Jack; BarrelJack_Horizontal
J3: Binding posts; Binding Posts
JP1: Min Lim; PinHeader_1x02_P2.54mm_Vertical
JP2: No limit; PinHeader_1x02_P2.54mm_Vertical
JP3: Preload; PinHeader_1x02_P2.54mm_Vertical
JP4, JP5: Guard; Guard_Jumper
R1: 1R8; R_1206_3216Metric_Pad1.42x1.75mm_HandSolder
R2: 4R7; R_1206_3216Metric_Pad1.42x1.75mm_HandSolder
R3: 13R; R_1206_3216Metric_Pad1.42x1.75mm_HandSolder
R4: 27R; R_1206_3216Metric_Pad1.42x1.75mm_HandSolder
R5: 68R; R_1206_3216Metric_Pad1.42x1.75mm_HandSolder
R6, R14: 100R; R_1206_3216Metric_Pad1.42x1.75mm_HandSolder
R7: 180R; R_1206_3216Metric_Pad1.42x1.75mm_HandSolder
R8, R10, R11, R12: 1R0; R_1206_3216Metric_Pad1.42x1.75mm_HandSolder
R9: 2R2; R_1206_3216Metric_Pad1.42x1.75mm_HandSolder
R13: 39R; R_1206_3216Metric_Pad1.42x1.75mm_HandSolder
R15: 4k7; R_Axial_DIN0207_L6.3mm_D2.5mm_P10.16mm_Horizontal
R16: 390R; R_Axial_DIN0207_L6.3mm_D2.5mm_P10.16mm_Horizontal
R17: 1k5; R_1206_3216Metric_Pad1.42x1.75mm_HandSolder
R18: 1M; R_1206_3216Metric_Pad1.42x1.75mm_HandSolder
R19: 24k; R_1206_3216Metric_Pad1.42x1.75mm_HandSolder
R20, R26: 1k; R_1206_3216Metric_Pad1.42x1.75mm_HandSolder
R21: 150k; R_1206_3216Metric_Pad1.42x1.75mm_HandSolder
R22: 1k; R_Axial_DIN0207_L6.3mm_D2.5mm_P10.16mm_Horizontal
R23: 22R; R_Axial_DIN0207_L6.3mm_D2.5mm_P10.16mm_Horizontal
R24, R25: 10k; R_1206_3216Metric_Pad1.42x1.75mm_HandSolder
R27, R28: 100R; R_Axial_DIN0207_L6.3mm_D2.5mm_P10.16mm_Horizontal
RV1: 100R; Trim_pot_Bourns_TC33X-2-101E
RV2: 500k; Potentiometer_Piher_PC-16_Single_Horizontal
RV3: 10k; Potentiometer_Piher_PC-16_Single_Horizontal
RV4: 1k; Potentiometer_Piher_PC-16_Single_Horizontal
RV5: 500k; Trim_pot_Bourns_TC33X-2-101E
SW1, SW2: SW_SP4T; SP4T_CK_SK-14D01-G-6
SW3: Lever toggle; SW_SPST_Lever_Rubber
TP1: Vin; TestPoint_Bridge_Pitch2.54mm_Drill1.3mm
TP2: Vout; TestPoint_Bridge_Pitch2.54mm_Drill1.3mm
TP5: Gnd; TestPoint_Bridge_Pitch2.54mm_Drill1.3mm
U1: LM4040DBZ-2.5; SOT-23
U2: LT3081; HTSSOP-16-1EP_4.4x5mm_P0.65mm_EP3.4x5mm_Mask3x3mm_ThermalVi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
U3: LM393; SOIC-8_3.9x4.9mm_P1.27mm
U4: LM334M; SOIC-8_3.9x4.9mm_P1.27mm
U5, U6: LM317L_TO92; TO-92_Inline

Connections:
GND: C2.1, C3.2, C4.2, C5.1, C6.1, C7.1, C8.2, J1.2, J2.2, J3.2, JP3.2, R18.2, R20.2, R24.2, R25.2, R26.2, RV3.2, RV3.3, TP5.1, U1.2 (A), U3.4 (V-)
Iout: C6.2, R24.1, R25.1, U2.10 (Imon)
unnamed: C1.1, SW1.5, SW2.3
unnamed: C1.2, JP2.1, JP4.2
unnamed: C2.2, JP5.2, R17.1, RV2.1
unnamed: D1.1 (K), U3.1
unnamed: D1.2 (A), R27.2, U5.1 (ADJ)
unnamed: D2.1 (K), U3.7
unnamed: D2.2 (A), R28.2, U6.1 (ADJ)
unnamed: J1.1, J2.1, SW3.1 (A)
unnamed: JP1.1, JP2.2, R1.2, R2.1, R3.1, R4.1, R5.1, R6.1, R7.1, RV4.3
unnamed: JP3.1, R23.2, U4.2, U4.3, U4.6, U4.7
unnamed: JP4.1, U2.6 (Ilim)
unnamed: JP5.1, U2.7 (SET)
unnamed: R1.1, R8.1
unnamed: R2.2, R9.1
unnamed: R8.2, SW1.1
unnamed: R9.2, SW1.2
unnamed: R3.2, R10.1
unnamed: R10.2, SW1.4
unnamed: R4.2, R11.1
unnamed: R11.2, SW2.1
unnamed: R5.2, R12.1
unnamed: R12.2, SW2.2
unnamed: R6.2, R13.1
unnamed: R13.2, SW2.4
unnamed: R7.2, R14.1
unnamed: R14.2, SW2.5
unnamed: R15.1, R19.2, U1.1 (K)
unnamed: R16.1, RV1.3
unnamed: R16.2, SW1.3
unnamed: R17.2, R18.1, U3.2 (-)
unnamed: R19.1, R20.1, U3.6 (_)
unnamed: R21.1, RV5.3, U3.3 (+)
unnamed: R22.1, U3.5 (+)
unnamed: R23.1, U4.1
unnamed: R27.1, U5.2 (VO)
unnamed: R28.1, U6.2 (VO)
unnamed: RV2.2, RV2.3, RV3.1
TEMP: C7.2, R22.2, R26.1, U2.11 (TEMP)
Vin: C4.1, C5.2, R15.2, SW3.2 (B), TP1.1, U2.12 (IN), U2.13 (IN), U2.14 (IN), U2.15 (IN), U3.8 (V+), U5.3 (VI), U6.3 (VI)
Vout: C3.1, C8.1, J3.1, JP1.2, R21.2, RV1.1, RV1.2, RV4.1, RV4.2, RV5.1, RV5.2, TP2.1, U2.1 (OUT), U2.2 (OUT), U2.3 (OUT), U2.4 (OUT), U2.5 (OUT), U2.8 (OUT), U2.9 (OUT), U2.16 (OUT), U2.17 (OUT), U4.4

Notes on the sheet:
2019-06-01
Simple Lab Power Supply
1 mA
2.5 mA
5 mA
10 mA
25 mA
50 mA
100 mA
1 mV/°C
*** The combination of the divider on V- and the voltage increase into V+ due to input bias current should provide adequate offset over the full range of Vin so that the output of the comparator is stable, but does not false-trigger due to Vout regulation tolerance.
***
** Ceramic X5R or X7R.
* 1% tolerance or better. 5-10% otherwise.
3.118 mA
(Optional all *)
1 mV/mA
10-turn
(opt; omit switches)
Trimmer
(opt)

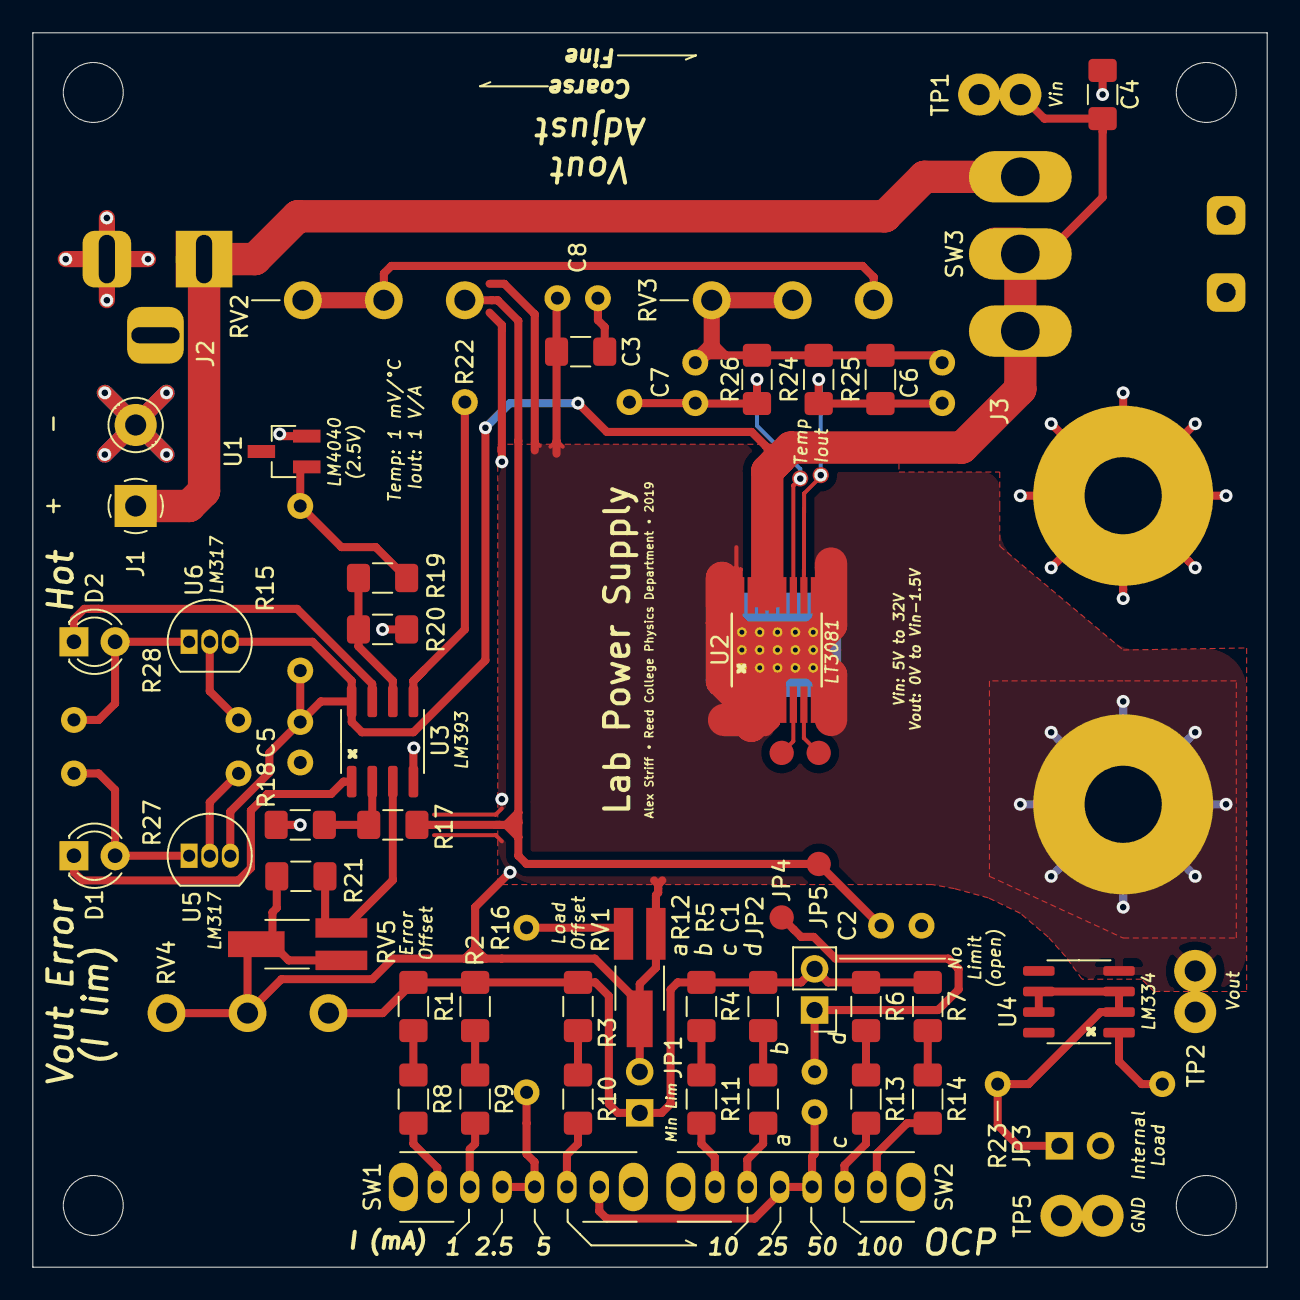
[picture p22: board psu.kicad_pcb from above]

Board: 2 copper layers, 76.2 x 76.2 mm, 63 parts (0 on the bottom side), 42 nets.

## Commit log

2019-05-31 New project
    [psu.kicad_pcb, psu.sch]
2019-06-04 Start Rev A
    The LT3081 does it all.
    [psu.sch]
2019-06-04 Closer to final; need offset
    Need to deal with input offset for current protection / regulation comparator. Add an adder before the comparator?
    [psu.sch]
2019-06-05 Rev A schematic finished!
    May need to slightly tweak resistor values based on available stock.
    [psu.sch]
2019-06-05 Finalization of resistor values
    [bom.csv, psu.sch]
2019-06-06 Most footprints entered
    [psu.sch]
2019-06-06 Finished footprints
    Also decided to use a comparator instead of the LM358 (would not handle inputs above Vin).
    [psu.sch]
2019-06-07 Started routing
    [psu.sch]
2019-06-07 Minor schematic tweaks; more routing
    [psu.kicad_pcb, psu.sch]
2019-06-07 Mostly routed
    [psu.kicad_pcb, psu.sch]
2019-06-08 More routing; some issues
    [psu.kicad_pcb, psu.sch]
2019-06-09 It's all connected man
    [psu.kicad_pcb, psu.sch]
2019-06-10 Silkscreen overhaul
    [psu.kicad_pcb]
2019-06-11 More silkscreen
    [psu.kicad_pcb]
2019-06-11 Fixed some 90 degree track-plane junctions
    [psu.kicad_pcb]
2019-06-11 Cleaned up silkscreen
    [psu.kicad_pcb]
2019-06-12 Final changes before manufacture
    [psu.kicad_pcb]
2019-06-12 Minor tweak to Vout fill; add gerbers
    [psu-B_Cu.gbr, psu-B_Mask.gbr, psu-B_SilkS.gbr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]
2019-06-12 Add PCB and datasheet PDFs
    [psu.sch]
2019-06-12 Added BOMs, a README, and started the manual
    [bom.csv, psu-digikey-bom.csv, psu-kicad-bom.csv]
2019-06-14 Added schematic, PCB layers, and BOM to manual
2019-06-15 Started to explain offset circuit
2019-07-08 Rev B
    [psu.sch]
